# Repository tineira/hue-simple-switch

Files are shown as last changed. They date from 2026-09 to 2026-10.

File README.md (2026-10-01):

# hue-simple-switch

Wi‑Fi wall switch for the **Seeed XIAO ESP32-C6**. Calls the Hue Bridge's local Clip v2 API (HTTPS). Not Zigbee.

GPIO channels (closed = pin to GND, `INPUT_PULLUP`):

| id | GPIO | default kind | label |
| --- | --- | --- | --- |
| `boot` | 9 | `momentary` | BOOT |
| `d0` | 0 | `maintained` | D0 |
| `d1` | 1 | `maintained` | D1 |
| `d2` | 2 | `maintained` | D2 |
| `d3` | 21 | none | D3 |
| `d4` | 22 | none | D4 |
| `d5` | 23 | none | D5 |

D3–D5 (GPIO 21–23) are channels since 0.5.0, so one board takes up to six wall switches or buttons on D0–D5, plus BOOT. None of D3–D5 is a strapping pin, and this firmware has no I2C on D4/D5. D6–D10 stay unused (D6 is the chip's serial TX at boot).

Since 0.3.0 the console picks each channel's kind (`maintained` = toggle switch, `momentary` = push button) and sends it in the config's `channels[]`; a pin it does not list does nothing. BOOT is always a push button. The default kinds above apply only to the old config payload (no `channels[]`), from a console that predates channel types; there D3–D5 do nothing, so an unwired pin never acts.

Each channel has recipes per event, derived by the console:

- Toggle switch, flip set (the lever sets on or off; no `flip` in `channels[]`): `on` (lever closes), `off` (lever opens, after the ~400 ms double-click window), `double_click` (opens and closes inside the window; runs `on` when there is no `double_click` recipe).
- Toggle switch, flip toggle (`"flip": "toggle"`, since 0.8.0; each flip toggles, the console sends `toggle` for both `on` and `off`): each flip posts `on` (lever closes) or `off` (lever opens) at once when there is no `double_click` recipe. With one, a flip either way waits ~400 ms: a second flip inside it is `double_click`, otherwise the first flip runs. No `on` fallback. A toggle that turned the lights off restarts the scene list. Boot, a config change or a change of the flip setting never toggles.
- Push button: `short` on release, at once when the channel has no `double_click` recipe; with one, a second press inside ~400 ms is `double_click` and an expired window is `short`. `hold` fires once at ~800 ms while pressed, only when the channel has a `hold` recipe.
- BOOT without a `hold` recipe: a 3 s press re-pairs with the Bridge. With one, the button never re-pairs (USB install only).
- A scene list (`recall_scene` with `targets[]`) cycles from the last scene the channel set (kept in NVS), wraps, skips scenes that answer 404, and starts over at the first scene after an `off` on the channel (in flip toggle mode, after a toggle that turned the target off).

The GPIO runs NVS → Bridge; it doesn't wait for Vercel. Since 0.5.0 the config is stored as one NVS blob per channel, so saving the largest config (seven channels with scene lists) needs only one channel's worth of free space; the first boot after the update converts the older single blob.

Wiring for up to six wall switches or buttons on D0–D5: [`docs/wiring-switches.svg`](docs/wiring-switches.svg). Wire only the inputs you use. The step-by-step build guide (what to buy, wiring one input at a time, what never to connect, and when you need the resistors) is at [hue.tineira.com/how-to](https://hue.tineira.com/how-to?product=simple#wire).

To power the switch from the mains inside a wall box, behind the existing switch, there is a carrier board (KiCad, Gerbers for JLCPCB, BOM) and a printable enclosure in [`hardware/`](hardware/README.md). It keeps the same pins and firmware. It is an uncertified, experimental mains design: read its safety notes and have an electrician install it.

> [!WARNING]
> **Safety.** Mains voltage can kill. The designs in this repository are uncertified and some are unproven, and the maintainer is not an electrical engineer. Rules and wire colors differ by country. Read the [Safety notice](https://hue.tineira.com/safety) before you build anything, and never connect any pin of a USB-powered build to anything that is or was on mains. Everything here is provided as is, without warranty, as the licenses say.

**BOOT** (GPIO9) and **RST** (CHIP_PU) are **buttons**, not LEDs. The board has two lights:

The orange LED's alphabet is **implemented** in firmware 0.2.7: `docs/specs/finished/led-status.md`.

| Light | Where | Driven by |
| --- | --- | --- |
| Orange (user, GPIO15 `LED_BUILTIN`) | Right side, next to RST | This firmware |
| Red (charging) | Next to the USB-C | The charger hardware; the sketch doesn't touch it |

### Orange LED (firmware)

One pattern at a time, top to bottom. When the step changes, the burst starts from zero. `LOW` on GPIO15 turns the orange on (active low).

| What you see | Meaning |
| --- | --- |
| Solid on | System error: the console task wasn't created, or the console answered 401. The 401 stays solid until a response with a code other than 401, or a new `HUESET token`. Wins even without Wi‑Fi. |
| Continuous blink ~2 Hz (250 ms on / 250 ms off) | No Wi‑Fi STA, or Improv scan. Even with a saved SSID. |
| 2 flashes and a pause | Wi‑Fi ok, no console (URL or token empty, or a `your-…` placeholder). |
| 3 flashes and a pause | Wi‑Fi and console, Hue not paired, or pairing in progress / timed out. Holding BOOT 3 s (re-pair) uses this pattern. |
| 4 flashes and a pause | Wi‑Fi, console and Hue, no recipes. |
| One short flash every ~3 s | Armed: one or more recipes. |

Burst (#2–#4): 100 ms on, 200 ms between flashes, 1400 ms pause. The armed flash lasts 80 ms and repeats every 3 s.

### Red LED (charging, not the sketch)

| What you see | Meaning |
| --- | --- |
| On for ~30 s when USB is plugged in without a battery | USB present; then it turns off. |
| Blinking | LiPo battery connected and charging over USB. |
| Off with USB and battery | Charge complete (or no charge cycle). |

Contract: `hue-switch-console/docs/definitions.md` and `docs/device-api.md`.

## Setup

1. Flash and provision from Chrome on [hue.tineira.com](https://hue.tineira.com) → Devices (USB). Improv saves the **2.4 GHz** network and `HUESET` stores the token (`hsw_…`) and url in NVS `console`. None of that is compiled in. For development, copy `config.example.h` to `config.h` (only `SERIAL_DEBUG`); `arduino-cli upload` doesn't erase NVS, so the network and token survive every flash.
2. The XIAO discovers the Bridge (mDNS `_hue._tcp`, NVS, `discovery.meethue.com`) and pairs the Hue key (three orange flashes → Bridge button). IP and key stay in NVS, not in `config.h`.
3. Register: `POST /api/device/register` with `product: "simple"`, MAC, `channels[]` and snapshot (lights/rooms/scenes). Poll: `GET /api/device/config?mac=&rev=&firmware=` at boot, then every `X-Poll-Sec` seconds from the console (clamped 30 s to 1 h; `204` = unchanged, keep NVS), once more right after a new `rev` is saved, and 1 h after a `401`. Without the header (older console): ~1 min without recipes, 1 h with some. With recipes, register (topology) at most hourly.
4. Arduino IDE 2.3.10: open `hue-simple-switch.ino`, board **XIAO_ESP32C6**.
5. Or arduino-cli: `arduino-cli compile --profile xiao-c6 .`

List lamps (diagnostics):

```
curl -k -H "hue-application-key: KEY" https://BRIDGE_IP/clip/v2/resource/light
```

`config.h` is not committed. Product onboarding = the USB installer on hue.tineira.com.

## Release

A push to `main` **is a release**. `.github/workflows/firmware.yml` builds the product image and uploads it to the console (hue.tineira.com) with this version's `CHANGELOG.md` entry as release notes. The console's USB installer then offers that build to every Simple plugged in over USB, and since 0.6.0 the owner can send it over Wi-Fi from the Switches page (below). The workflow also keeps the `usb-installer` GitHub Release as a download link. Pushes that change only docs or the board design (`*.md`, `docs/`, `hardware/`) do not run it, except `CHANGELOG.md`, which re-sends the notes. To skip any other push, put `[skip ci]` in its commit message.

- `FIRMWARE_VERSION` in `console.h` is the version the console shows. Bump it for any change a board should pick up, and add its entry to `CHANGELOG.md` in the same commit. A push without a bump re-sends the notes only (`409 version_exists` warning).
- `THIRD_PARTY.json` lists the open-source components linked into the image (the core, ESP-IDF, and every library pinned in `sketch.yaml`), with version, SPDX license and a link to the license at that version. CI sends it as the release `credits` for the console's Credits page, and fails if any `platform:` or `libraries:` entry in `sketch.yaml` is missing from it or has a different version (`scripts/check-credits.py`, run on every pull request too). Update it in the same commit as any core or library bump.
- Update over Wi-Fi (0.6.0+, console `docs/specs/ota.md`): when the owner presses Update, the next poll's `200` carries `ota` (version, path, sha256, size). After the poll's connection is closed, the console task downloads `firmware.bin` from the console URL in NVS, writes it to the inactive app slot while hashing it, checks length and sha256, and restarts into it. It waits for the next poll while an input is pressed or a Hue call is queued or running. The new image confirms itself after its first `200`/`204` poll; a restart before that makes the bootloader go back to the old one, which reports `ota_error=boot`. A failure is reported once as `ota_error` and retried at most hourly (a download cut off by a power cut or restart counts, reported as `size` at the next boot, since 0.6.1) (`size`/`sha` from a bad image: not until reboot). NVS is never erased. Boards before 0.6.0 need one USB update first.
- Image layout and offsets: [`docs/firmware-artifacts.md`](docs/firmware-artifacts.md).
- The pipeline needs the `FIRMWARE_UPLOAD_TOKEN` secret in this repo. Setup and troubleshooting: the console repo's `README.md`, "Firmware release pipeline".

### Build and upload from a fork

A fork builds the same image on every push to its `main`, and can upload it to your own console instead of hue.tineira.com (self-hosting: the console repo's `docs/self-hosting.md`).

- **Build only (default).** With no `FIRMWARE_UPLOAD_TOKEN` secret, the workflow builds, skips the upload with a notice and stays green. The four installer parts are in the run's `usb-installer-simple` artifact and in the fork's `usb-installer` GitHub Release.
- **Upload to your console.** In the fork's **Settings → Secrets and variables → Actions**:
  1. Add the repository **variable** `CONSOLE_UPLOAD_URL` with your console's origin, for example `https://hue.example.com` (no path, no trailing slash). Without it, the upload goes to `https://hue.tineira.com`, which rejects a fork's token.
  2. Add the repository **secret** `FIRMWARE_UPLOAD_TOKEN` with the value of `FIRMWARE_UPLOAD_TOKEN` on your console.
  3. Push to `main` (or run the workflow by hand). The release waits in your console's `/admin` until you make it current; Setup then flashes it.
- Bump `FIRMWARE_VERSION` in `console.h` and add its `CHANGELOG.md` entry for each build you want boards to get, as above: your console keeps the first bins it received for a version.

## Contributing

See [`CONTRIBUTING.md`](CONTRIBUTING.md). Bugs and ideas go in GitHub issues.

## Sponsor

The console and the switch firmwares are free and stay that way. If they are useful
to you, you can [sponsor the project on GitHub](https://github.com/sponsors/tineira).
Sponsorship helps pay for development and does not unlock anything.

## License

Copyright (c) 2026 Tomas Neira and contributors. [MIT](LICENSE), except the
carrier board and enclosure designs in `hardware/`, which are
[CERN-OHL-P-2.0](hardware/LICENSE) (see [`hardware/README.md`](hardware/README.md)).

The image also links open-source components under their own licenses, listed in
[`THIRD_PARTY.json`](THIRD_PARTY.json). The Arduino-ESP32 core is LGPL-2.1-or-later:
because this firmware's source is public, you can rebuild it against a modified core.

The console this firmware talks to, [`hue-switch-console`](https://github.com/tineira/hue-switch-console),
is AGPL-3.0; it also holds the device contract (`docs/device-api.md`).

Not affiliated with or endorsed by Signify. Philips Hue is a trademark of Signify.

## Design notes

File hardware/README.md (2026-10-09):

# Mains carrier board and enclosure

A small board that puts the XIAO ESP32-C6 and its own power supply inside a wall
electrical box, powered from the mains, reading the existing wall switches or
buttons on D0 to D5. Firmware, pin map and console contract are unchanged: this
is the same `hue-simple-switch`, with a different way to power and wire it.

> [!WARNING]
> **Mains voltage can kill.** This is an uncertified design, produced with AI
> assistance and checked only by the design-rule tools listed below. It has not
> been tested by a lab and carries no approval mark (CE, UL, SEC or other).
> Have a qualified electrician install it. Switch the circuit off at the
> breaker before opening the box, and check it is dead with a tester.
> Build and install it at your own risk.
>
> - **Status: experimental.** The first boards came back from JLCPCB in
>   October 2026. One passed the checks in [TESTING.md](TESTING.md) and runs
>   on mains with the XIAO, showing in the console. None has been installed
>   in a wall yet. Expect mistakes.
> - The maintainer is not an electrical engineer. This is a hobby design.
> - Rules and wire colors differ by country and with the age of the wiring.
>   Identify every conductor by testing it, never by its color. In some
>   countries only a licensed electrician may change fixed wiring.
> - An uncertified device in your home's wiring may affect your home insurance.
>
> Read the full [Safety notice](https://hue.tineira.com/safety) before you order
> anything.

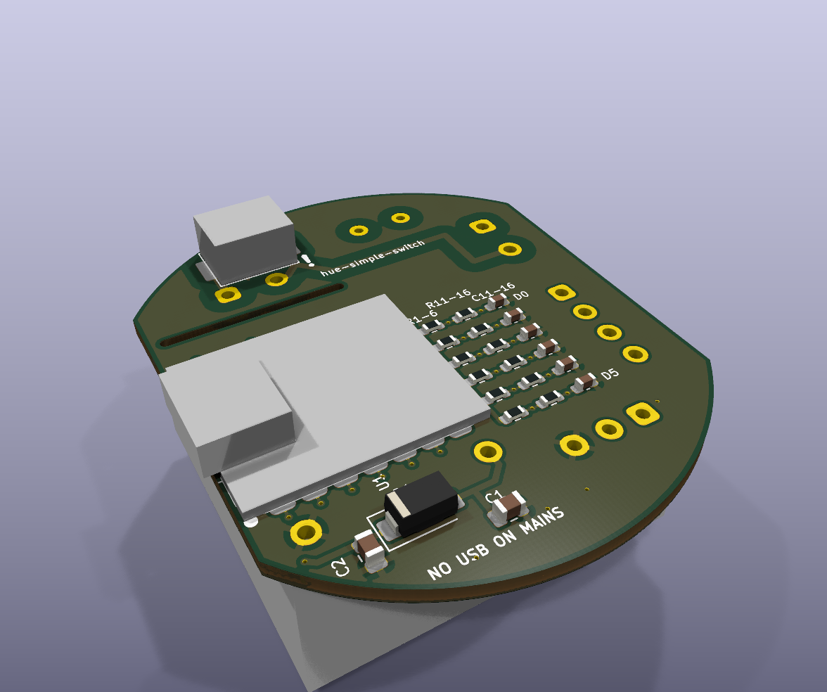
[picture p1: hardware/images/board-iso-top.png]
Top (XIAO side)

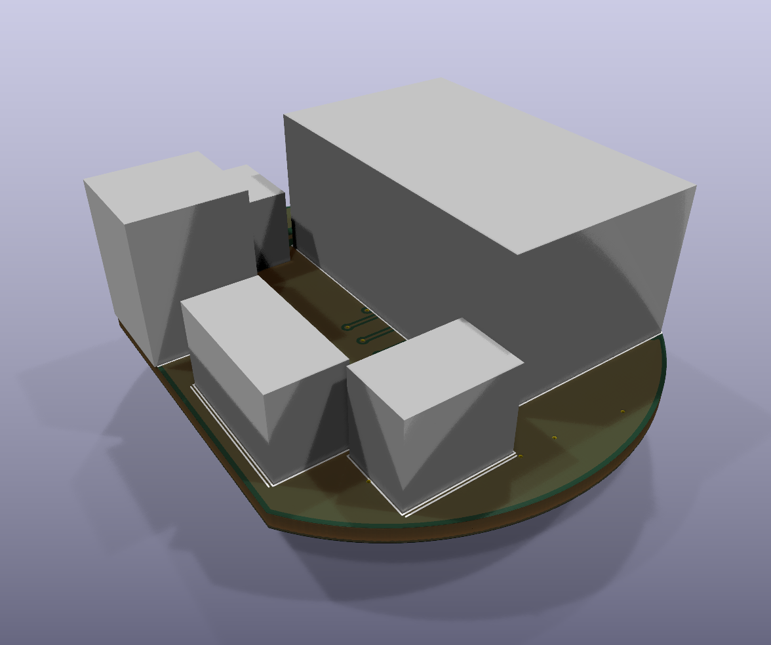
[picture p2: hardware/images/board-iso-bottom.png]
Bottom (power side)


The XIAO has no 3D model in these renders. It sits flat on the top side, USB-C
at the left edge.

## What is on the board

| Part | What it does |
| --- | --- |
| J1, 2-way 5.08 mm screw terminal | Mains in: L and N (up to 2.5 mm²) |
| F1, T500 mA TR5 fuse | Protects the wiring if the module or varistor fails |
| RV1, TDK SIOV CU3225 275 VAC SMD varistor (8.0 × 6.3 × 4.5 mm) | Clamps mains surges at the module input, after the fuse |
| PS1, Hi-Link HLK-PM01 | Certified, sealed, isolated 100-240 V AC to 5 V DC module (3 kV AC isolation) |
| D1, SS34 Schottky diode | Feeds the XIAO's 5V pin; stops a USB cable from powering the module backwards |
| U1, XIAO ESP32-C6 | Soldered flat by its edge pads |
| J2 + J3, 3.5 mm screw terminals | Wall switch inputs **D0 D1 D2 D3** and **D4 D5 GND**. Low voltage (3.3 V) only |
| R1-R6, R11-R16, C11-C16 | Each input: 10 kΩ pull-up at the pin, 1 kΩ in series, 10 nF at the terminal |

The pin map is the firmware's (see the repo [README](../README.md) and
[`docs/wiring-switches.svg`](../docs/wiring-switches.svg)): D0 to D5 are GPIO 0, 1,
2, 21, 22 and 23. A closed switch pulls its pin to GND. BOOT (hold 3 s to re-pair
with the Hue Bridge) and RESET are the XIAO's own buttons, reachable through the
window in the lid.

Isolation: everything connected to L or N is kept at least **6 mm** (clearance
and creepage, checked by DRC) from everything else. A routed slot under the
power module separates its AC pins from the XIAO. The only link between the two
sides is the HLK-PM01 itself.

The console's build guide has a short "can I use it?" check, a before-and-after wiring drawing and the installation order to show your electrician: [hue.tineira.com/how-to](https://hue.tineira.com/how-to?product=simple#in-wall).

Schematic: [`fab/hue-simple-switch-mains-schematic.pdf`](fab/hue-simple-switch-mains-schematic.pdf).

## Does it fit my box?

Enclosure outside: **46 × 56 mm, 26 mm tall** (a Ø56 mm disc with two sides cut
flat at 46 mm). It sits **behind the switch mechanism** in the same box, so the
box needs about 26 mm of free depth behind the mechanism.

| Box | Interior (typical) | Behind a mechanism |
| --- | --- | --- |
| EU round, Ø60 mm (DIN 49073) | Ø60 × 40 mm, or 60 to 65 mm deep | Deep box (≥ 60 mm) only. A standard 40 mm box is too shallow |
| US single gang | about 51 × 76 mm, 2.5 to 3.5 in deep | Yes, in most boxes |
| UK 86 × 86 (BS 4662) | 75 × 75 mm, 25, 35 or 47 mm deep | 47 mm box only |
| Chile, rectangular for Italian-style plates | about 50 × 95 mm, 40 to 50 mm deep | No room behind a mechanism, but it fits **beside** a 1-module mechanism, in the space of two blank modules (56 mm along the box) |

The Chilean dimensions come from retail listings, not a standard. Measure your
box: the width across the flats (46 mm) and the depth are what matter. In a
metal box, Wi-Fi range drops a lot; plastic boxes are better.

## Before you install: requirements

- **A neutral wire in the box.** The power module needs L and N. Many switch
  boxes (in Chile, and in older US and European homes) only have the switched
  live and the live feed, with no neutral. Without a neutral this board cannot
  be used. There is no safe no-neutral version for this design.
- **The Hue bulbs must be powered all the time.** The wall switch no longer
  switches the lamp; the lamp's live is joined straight through (as the
  existing Hue setup already requires).
- **The switch wires must be completely disconnected from the mains.** The
  wires that run from the box to each switch or button were mains wires. After
  the conversion they carry only 3.3 V from J2/J3. Every one of them must be
  disconnected from L, N and the lamp at both ends, and must go only to the
  switch and to J2/J3. If any of them still touches mains anywhere, the XIAO,
  and anyone touching its USB port, will be at mains voltage. An electrician
  must check this.

## Order assembled boards (JLCPCB)

JLCPCB assembles everything except the XIAO, on a panel of three boards.
All SMD parts are on the XIAO side (one-sided assembly); the power module, fuse
and terminals are through-hole on the other side.

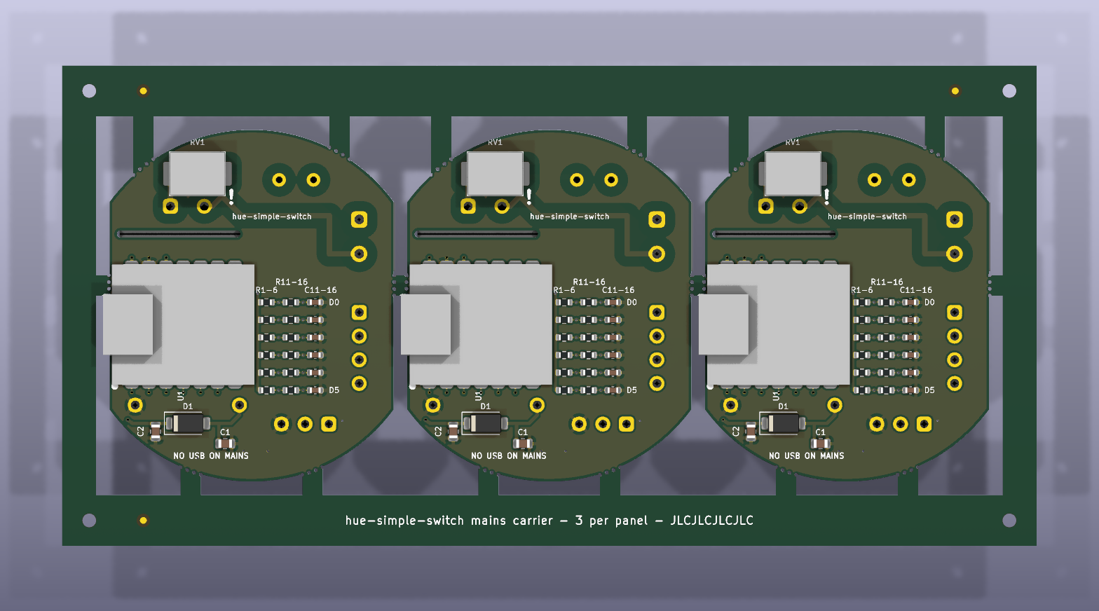
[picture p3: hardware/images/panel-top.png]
3-board panel


1. At jlcpcb.com, upload
   [`fab/jlcpcb/hue-simple-switch-mains-panel-gerbers.zip`](fab/jlcpcb/hue-simple-switch-mains-panel-gerbers.zip).
   The panel is 144 × 71 mm (three boards, a frame with fiducials and tooling
   holes; each board held on six tabs with mouse bites: two on each round end
   and one on each straight side, so the row stays stiff during assembly). Defaults: 2 layers, 1.6 mm FR-4,
   1 oz copper, HASL. Choose **Panel by customer** (the frame is already there,
   so no edge rails or panelizing by JLCPCB) and quantity **5** = 15 boards.
2. Turn on PCB Assembly, top side, and upload
   [`fab/jlcpcb/hue-simple-switch-mains-panel-bom.csv`](fab/jlcpcb/hue-simple-switch-mains-panel-bom.csv)
   and [`fab/jlcpcb/hue-simple-switch-mains-panel-cpl.csv`](fab/jlcpcb/hue-simple-switch-mains-panel-cpl.csv).
   Designators end in the board number (`R1_1`, `R1_2`, `R1_3`). The XIAO (U1)
   is not in them. Add through-hole assembly for PS1, F1 and J1-J3.
3. In the preview, check the parts listed under [Check in JLCPCB's
   preview](#check-in-jlcpcbs-preview). The CPL gives each part's centre (the
   middle of its pads), so parts should sit on their pads; rotate any that do not.
4. Small SMD parts need a few spares for machine loss (attrition). JLCPCB takes
   the basic resistors and capacitors from its stock; for the varistor (an
   extended part) have a couple more than 15 in your parts inventory.

To have JLCPCB assemble single boards instead of the panel, upload
[`fab/hue-simple-switch-mains-gerbers.zip`](fab/hue-simple-switch-mains-gerbers.zip),
[`fab/jlcpcb/hue-simple-switch-mains-single-bom.csv`](fab/jlcpcb/hue-simple-switch-mains-single-bom.csv)
(no XIAO) and [`fab/hue-simple-switch-mains-cpl.csv`](fab/hue-simple-switch-mains-cpl.csv).
The board is under JLCPCB's 70 × 70 mm minimum, so they add edge rails at extra cost.

For hand assembly, the single board is in
[`fab/hue-simple-switch-mains-gerbers.zip`](fab/hue-simple-switch-mains-gerbers.zip)
with [`fab/hue-simple-switch-mains-bom.csv`](fab/hue-simple-switch-mains-bom.csv)
and [`fab/hue-simple-switch-mains-cpl.csv`](fab/hue-simple-switch-mains-cpl.csv).

### Check in JLCPCB's preview

Parts with a polarity or a direction that matters:

| Part | What must be right |
| --- | --- |
| D1, SS34 diode (top) | Cathode band towards pad 1, the left pad (towards C2 and the board's left edge). Reversed, the XIAO gets no power |
| PS1, HLK-PM01 (bottom) | The two pins 5 mm apart (AC) at the mains end, next to the fuse and RV1; the two pins 15.4 mm apart (DC) at the other end. The pin pattern only fits one way, so if the preview shows pins off the holes, rotate it until all four land |
| J1, J2, J3, screw terminals (bottom) | The wire openings face the board edge: J1 and J2 towards the straight right edge, J3 towards the round end. Turned 180° they still fit the holes but face inwards, so check this one by eye (tilt the 3D view: the side you see from the middle of the board must be the back, not the metal clamps). JLCPCB's models for J2 and J3 are drawn the other way round from KiCad's, so the CPL already adds 180° to those two |
| U1, XIAO (you solder it) | Component side up, USB-C over the left board edge |

Not polarised: every resistor, the 10 nF and 22 µF ceramic capacitors, the
varistor RV1 and the fuse F1. They only need to sit on their pads.

When the panels arrive, snap the boards out at the mouse bites (bend each tab
towards the side without parts, or cut it with side cutters) and file the stubs
flush. Keep them clear of the mains parts: the tabs are at least 1 mm from any
mains copper.

## Check the board

Before the XIAO goes on and before the board sees mains, check it with a
multimeter: continuity on the mains side, isolation between mains and the
low-voltage side, the input resistors, and a first power-up through a lamp in
series. The steps, the expected readings and the readings from the first board
are in [TESTING.md](TESTING.md).

## Solder the XIAO

1. **Flash and set up the XIAO over USB before you solder it** (next section).
   It is easier on its own, and afterwards the board should not be on USB at the
   same time as mains.
2. Solder it flat on the top side, USB-C over the left board edge. Solder all 14
   edge pads (only D0-D5, 5V, GND and 3V3 are used; the others hold it in
   place). Do not let solder bridge to the bare pads under the XIAO; the board
   has no copper under it.
3. Inspect the mains side with a magnifier: no solder balls, splashes or flux
   bridges between L, N and anything else. Trim the through-hole leads on the
   top side to 1.5 mm or less so they do not touch the lid.

## First setup (USB, never on mains)

Do this with the board **not connected to mains** (before soldering the XIAO,
or with J1 disconnected):

1. Flash and provision it over USB-C like any other hue-simple-switch: Chrome
   on [hue.tineira.com](https://hue.tineira.com) → Devices (see the main
   [README](../README.md)). Then pair the Hue Bridge.
2. Unplug USB.

After installation, updates come over Wi-Fi (firmware 0.6.0 and newer), so USB
is never needed in the wall.

> [!CAUTION]
> **Never connect a USB cable while the board is connected to mains.** The power
> module is isolated, but a fault, a wrongly wired switch line or a damaged
> module would put mains on the USB cable and on your computer.

## Wire it

```text
 mains L (permanent live) ── J1 L          Hue lamps: live joined straight through,
 mains N ─────────────────── J1 N          not through the switch any more

 switch 1 ── J2 D0     switch 4 ── J2 D3
 switch 2 ── J2 D1     switch 5 ── J3 D4
 switch 3 ── J2 D2     switch 6 ── J3 D5
 other terminal of every switch, joined ── J3 GND
```

- Use only the inputs you need, and set each one up in the console (toggle
  switch or push button).
- The common return of all switches goes to the single GND terminal: join them
  first with a lever connector (for example WAGO 221) and bring one wire to J3.
- The screw terminals take up to 2.5 mm² (J1) and about 1 mm² (J2/J3). For
  1.5 mm² solid building wire on J2/J3, join a short 0.5-0.75 mm² flexible
  pigtail with a lever connector.
- Keep the switch wires on the low-voltage side of the enclosure (wire holes on
  the long straight side next to D0-D3, and the curved end next to D4-GND). The
  L/N holes are the two larger ones at the other end of the straight side.
- Earth (PE): the module does not need it. Connect the box's earth wires to each
  other as before, not to this board.

## Print the enclosure

- [`enclosure/enclosure-base.stl`](enclosure/enclosure-base.stl) and
  [`enclosure/enclosure-lid.stl`](enclosure/enclosure-lid.stl), both already
  oriented flat side down. No supports.
- Plastic: **not PLA** (it softens and creeps in a warm wall box). Use PETG, ASA
  or PC; ideally a flame-retardant (UL 94 V-0) grade. 0.2 mm layers, 3 walls,
  100 % infill for the floor.
- The board rests on posts in the base (power module down); the lid clicks over
  it and its posts hold the board down. The terminal screws are reached through
  the slots in the base floor. Tighten the wires before closing the lid, and
  put a strip of Kapton or electrical tape over the floor slots before the
  module goes into the wall.
- Source: [`enclosure/enclosure.scad`](enclosure/enclosure.scad) (OpenSCAD,
  parametric: wall, clearances, heights, hole sizes). The board as a 3D model is
  in `enclosure/hue-simple-switch-mains-board.step` for checking the fit in a
  CAD tool.

Layout of the enclosure, seen from the lid (XIAO side):

```text
            ┌─── round end ───┐
           /  MAINS: F1, RV1   \
          │  (module AC pins)   │  J1: L, N  ◄── two Ø3.6 wire holes
  USB-C ◄─┤  XIAO     ··········├─ J2: D0-D3 ◄── four Ø3.0 wire holes
 + window │  (over the module)  │
           \   J3: D4 D5 GND   /
            └──── ▼ three Ø3.0 wire holes
```

## Regenerate the files

Everything in `kicad/`, `fab/`, `images/` and the STLs is generated from
[`scripts/design.py`](scripts/design.py) (parts, nets),
[`scripts/layout.py`](scripts/layout.py) (placement, copper) and
[`scripts/footprints.py`](scripts/footprints.py) (footprints and height models
for the power module, varistor and terminal blocks, drawn from each
manufacturer's datasheet; the numbers are quoted in the file). Edit those, not
the KiCad files, then run with KiCad 10's own Python:

```bash
"$LOCALAPPDATA/Programs/KiCad/10.0/bin/python.exe" hardware/scripts/build_all.py
```

It writes the schematic and runs ERC, builds the PCB, refills the copper pours
and runs DRC with schematic parity (it stops on any error), then exports the
Gerber zip, BOM, CPL, PDFs, STEP, renders, builds the 3-board panel
([`scripts/build_panel.py`](scripts/build_panel.py)) and checks it with DRC
too, exports its JLCPCB files into `fab/jlcpcb/`, and, when OpenSCAD is
installed, the STLs. Reports: `fab/erc.rpt`, `fab/drc.rpt` (the remaining warnings are
silkscreen clipped at the board edge, which the fab trims anyway). The custom
6 mm rule is in `kicad/hue-simple-switch-mains.kicad_dru`.

You can also open `kicad/hue-simple-switch-mains.kicad_pro` in KiCad 10 to look
around; changes made there are lost at the next regeneration.

## Credits and licenses

- XIAO ESP32-C6 footprint: from Seeed Studio's
  [OPL_Kicad_Library](https://github.com/Seeed-Studio/OPL_Kicad_Library)
  (CC BY-SA 4.0), reduced to the 14 edge pads in `kicad/lib/XIAO.pretty`.
- Other symbols, footprints and 3D models: the KiCad libraries (CC BY-SA 4.0
  with the KiCad libraries exception).
- The board design and enclosure (`kicad/`, `fab/`, `enclosure/`, `images/`)
  are [CERN-OHL-P-2.0](LICENSE), a permissive open hardware license with a
  disclaimer written for physical hardware. The generator scripts in `scripts/`
  are software and stay MIT, like the rest of this repository.

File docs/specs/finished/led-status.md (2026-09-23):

# Simple switch — orange LED (status)

**Requirements** document. Covers only `hue-simple-switch` (XIAO ESP32-C6, GPIO15 `LED_BUILTIN`, orange). Round uses the disc, not this alphabet.

The red charging LED and the BOOT/RST buttons are not part of this spec.

**Status:** implemented (firmware 0.2.7). Spec archived. Not an implementation gap.

**Closed on 2026-09-21 (grilling):** tick during the POST, rejected key vs PUT, #6 only 401/task, burst restarts from zero. Do not reopen.

---

## 1. Who it's for

A **bench setup** checklist (the XIAO is visible). Inside the wall box the LED is hardly ever looked at; it's not everyday UI.

It doesn't teach *how* to configure. Only *which step you're on* or *there's a system fault*.

---

## 2. Steps (priority)

Evaluated **top to bottom**. The first that matches wins. One pattern at a time.

| # | Condition | Pattern |
| --- | --- | --- |
| 6 | **System** error (below) | Solid on |
| 1 | No Wi‑Fi STA (`WL_CONNECTED` false) | Continuous fast ~2 Hz |
| 2 | Wi‑Fi ok, no console URL or token in NVS `console` | **2** flashes, pause |
| 3 | Wi‑Fi + console, no paired Bridge (no usable Hue key in NVS, or pairing in progress / timed out) | **3** flashes, pause |
| 4 | Wi‑Fi + console + Hue, **zero** recipes in NVS | **4** flashes, pause |
| 5 | Armed: Wi‑Fi + console + Hue + ≥1 recipe | One short flash every ~3 s |

A 3 s BOOT hold (re-pair) shows **#3** while pairing lasts, not an extra pattern.

When the **step changes**, the pattern starts from zero (first flash, or the first half-cycle of #1/#5). The rest of a previous burst is not shown.

Improv scan or association (`WL_CONNECTED` false, even if NVS has an SSID) is **#1**. A token or URL that `consoleConfigured()` rejects (empty or malformed) is "no console" → **#2** if there is Wi‑Fi.

---

## 3. Timing (countable, not different frequencies)

Constants (ms), one table in code:

| Symbol | ms | Use |
| --- | --- | --- |
| `PULSE_ON` | 100 | Burst flash (#2–4) |
| `PULSE_GAP` | 200 | Off between flashes of the same burst |
| `BURST_PAUSE` | 1400 | Off after the last flash, before repeating |
| `FAST_ON` / `FAST_OFF` | 250 / 250 | #1 (~2 Hz). Not counted. |
| `HEART_ON` | 80 | #5 |
| `HEART_OFF` | 2920 | #5 → 3 s period |

Burst of *n* flashes: `n × PULSE_ON + (n − 1) × PULSE_GAP`, then `BURST_PAUSE`.

Example #3: on 100 — off 200 — on 100 — off 200 — on 100 — off 1400 — repeat. You count **three**.

#6: pin `LOW` (on), no blink tick.

Don't use 5 Hz vs 10 Hz vs 1 Hz. A human can't tell them apart on a 3 mm LED.

---

## 4. What a system error is (#6)

Closed list. Nothing else turns on the solid light:

- The console task was not created.
- The console answered **401** (token rejected). Recipes in NVS are kept.

The 401 **sticks** until a real console response with a code **> 0 and other than 401**, or until a new `HUESET token`. An attempt that doesn't arrive (timeout, `code == -1`, Wi‑Fi down) does **not** clear it. While it sticks, the solid light wins even without Wi‑Fi (#1 is not shown).

**Not** #6:

- Pairing timeout or Bridge not found → **#3**.
- Wi‑Fi down, no sticky 401 → **#1**.
- Failed Hue PUT on a GPIO touch (on/off/double/short), or unreachable Bridge → **the LED doesn't change**.
- Console poll, `rev`, snapshot, debounce, any `LOG`.

---

## 5. Hue "paired"

For #3 vs #4/#5: there is a key in NVS that `hueLooksLikeKey` accepts **and** a Bridge IP. Do **not** GET Clip on every LED tick.

It is lost, dropping to **#3**, only if a Hue HTTP call **that sent the key** says it's no good: **401 or 403**, and the body isn't "link button not pressed". A 401/403 from a request without the key (`/api/config`, discovery) doesn't count. A PUT that did carry the key and returns 401/403 does drop to #3. A timeout, a 5xx or the Bridge being off do **not** drop the step. Never #6.

For **20 s** after the pairing POST has just delivered the key, a 401 or 403 does **not** drop to #3. The key just came out of the Bridge. A later call, outside those 20 s, does.

---

## 6. Empty recipes

#4 = `gRecipeCount == 0` (no channel). One recipe on a single channel is already armed (#5). Don't distinguish "the other three are missing".

---

## 7. Boot

After `pinMode(LED_BUILTIN, OUTPUT)` the same classifier runs. The first few hundred ms may look like #1 (no STA yet). There is no separate `UI_BOOT` screen.

USB Improv / `HUESET` add no pattern: no STA → #1; STA without token/url (not yet in NVS) → #2.

---

## 8. Done in 0.2.7

- LED tick on a timer, **no `delay()`**, every **~50 ms**, also during the pairing POST. The GPIO doesn't wait for the LED (`channelsPoll` first).
- Pattern #3 is set by the classifier, not `hueBlink`.
- Polarity: `LOW` = on (GPIO15, active low). `HIGH` turns it off.
- The red charging LED is untouched.
- `FIRMWARE_VERSION` 0.2.7. The README table matches.

Outside this slice: Round (disc), Improv copy, console.

---

## 9. Bench test (acceptance)

With the XIAO in view, without opening Serial:

1. No SSID / Wi‑Fi down → continuous ~2 Hz.
2. Wi‑Fi, delete or empty URL/token → count **2**.
3. Wi‑Fi + console, BOOT hold 3 s or no key → count **3**; pressing the Bridge button moves to 4 or 5.
4. Paired, console without recipes → count **4**.
5. One recipe on any channel → one flash every ~3 s.
6. Invalid console token (401) → solid. Restore the token → back to 4 or 5.
7. During 4 or 5, a GPIO whose PUT fails → the pattern does **not** go solid.

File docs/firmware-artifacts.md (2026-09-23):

# Firmware artifacts (simple / ESP32-C6)

Product installer binary for hue.tineira.com. `SERIAL_DEBUG=0`. Wi-Fi, console URL and token are never compiled in: Wi-Fi is Arduino STA (Improv), token and URL go in NVS namespace `console` (`HUESET`). A dev `config.h` differs only in `SERIAL_DEBUG`.

## Compile

Sketch folder must be named `hue-simple-switch` (matches `hue-simple-switch.ino`). Profile: `sketch.yaml` `xiao-c6` (`esp32:esp32:XIAO_ESP32C6`, Arduino-ESP32 3.3.12). Partition table: sketch `partitions.csv` (min_spiffs: 1.9MB APP ×2, app at `0x10000`). USB CDC on boot is the board default.

```
copy config.product.h config.h
arduino-cli compile --profile xiao-c6 --export-binaries --build-property upload.maximum_size=1966080 .
```

`--export-binaries` writes under `build/esp32.esp32.XIAO_ESP32C6/`. `upload.maximum_size` matches the min_spiffs app slot (boards.txt still advertises the smaller default 4MB scheme).

Stage stable names in `dist/installer/` (gitignored; do not commit bins here):

| Export | Installer |
| --- | --- |
| `hue-simple-switch.ino.bootloader.bin` | `bootloader.bin` |
| `hue-simple-switch.ino.partitions.bin` | `partitions.bin` |
| `boot_app0.bin` | `boot_app0.bin` |
| `hue-simple-switch.ino.bin` | `firmware.bin` |

CI (`.github/workflows/firmware.yml`) copies `config.product.h` → `config.h`, compiles on push to `main` / `workflow_dispatch`, uploads those four files, and refreshes GitHub Release tag `usb-installer` (version `0.2.10`).

`FIRMWARE_VERSION` is `0.2.10` (see `console.h`).

## Manifest parts

`chipFamily`: `ESP32-C6`. Offsets from this compile’s `flash_args` (esptool write order). Do not erase flash (NVS survives).

| Part | File | Offset |
| --- | --- | --- |
| bootloader | `hue-simple-switch.ino.bootloader.bin` | `0x0` |
| partitions | `hue-simple-switch.ino.partitions.bin` | `0x8000` |
| boot_app0 | `boot_app0.bin` | `0xe000` |
| app | `hue-simple-switch.ino.bin` | `0x10000` |

Recorded from `arduino-cli compile --profile xiao-c6 --export-binaries` on 2026-09-20, core 3.3.12, `flash_args`:

```
--flash-mode dio --flash-freq 80m --flash-size 4MB
0x0 hue-simple-switch.ino.bootloader.bin
0x8000 hue-simple-switch.ino.partitions.bin
0xe000 boot_app0.bin
0x10000 hue-simple-switch.ino.bin
```

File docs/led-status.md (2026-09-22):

# Simple switch — LED naranja (status)

Documento de **requisitos**. **Implementado en firmware 0.2.7.** Cubre solo `hue-simple-switch` (XIAO ESP32-C6, GPIO15 `LED_BUILTIN`, naranja). Round usa el disco, no este alfabeto.

El LED rojo de carga y los botones BOOT/RST no forman parte de este spec.

**Estado (2026-09-21):** implementado en firmware 0.2.7.

**Cerrado el 2026-09-21 (grilling):** tick durante el POST, key rechazada vs PUT, #6 solo 401/task, ráfaga desde cero. No reabrir.

---

## 1. Para quién

Checklist de **alta en el banco** (se ve el XIAO). En la caja de la pared el LED casi no se mira; no es UI de uso diario.

No enseña *cómo* configurar. Solo *en qué peldaño estás* o *hay un fallo de sistema*.

---

## 2. Peldaños (prioridad)

Se evalúa **de arriba abajo**. El primero que cumpla gana. Un solo patrón a la vez.

| # | Condición | Patrón |
| --- | --- | --- |
| 6 | Error de **sistema** (abajo) | Encendido fijo |
| 1 | Sin Wi-Fi STA (`WL_CONNECTED` falso) | Rápido continuo ~2 Hz |
| 2 | Wi-Fi ok, sin `CONSOLE_URL` o sin `CONSOLE_TOKEN` (config.h ni NVS) | **2** destellos, pausa |
| 3 | Wi-Fi + consola, sin Bridge pareado (no hay key Hue usable en NVS, o pairing en curso / timeout) | **3** destellos, pausa |
| 4 | Wi-Fi + consola + Hue, **cero** recetas en NVS | **4** destellos, pausa |
| 5 | Armado: Wi-Fi + consola + Hue + ≥1 receta | Un destello corto cada ~3 s |

Hold 3 s en BOOT (re-pair) entra en **#3** mientras dura el pairing, no un patrón extra.

Al **cambiar de peldaño**, el patrón empieza de cero (primer destello, o el primer semiciclo de #1/#5). No se muestra el resto de una ráfaga anterior.

Scan Improv o asociación (`WL_CONNECTED` falso, aunque la NVS tenga SSID) es **#1**. Un token o URL que `consoleConfigured()` rechaza (vacío, o el placeholder `your-…` de `config.h`) es “sin consola” → **#2** si hay Wi-Fi.

---

## 3. Timing (contable, no Hertz distintos)

Constantes (ms), una sola tabla en código:

| Símbolo | ms | Uso |
| --- | --- | --- |
| `PULSE_ON` | 100 | Destello de ráfaga (#2–4) |
| `PULSE_GAP` | 200 | Apagado entre destellos de la misma ráfaga |
| `BURST_PAUSE` | 1400 | Apagado después del último destello, antes de repetir |
| `FAST_ON` / `FAST_OFF` | 250 / 250 | #1 (~2 Hz). No se cuenta. |
| `HEART_ON` | 80 | #5 |
| `HEART_OFF` | 2920 | #5 → periodo 3 s |

Ráfaga de *n* destellos: `n × PULSE_ON + (n − 1) × PULSE_GAP`, luego `BURST_PAUSE`.

Ejemplo #3: on 100 — off 200 — on 100 — off 200 — on 100 — off 1400 — repetir. Se cuentan **tres**.

#6: `digitalWrite` LOW, sin tick de parpadeo.

No usar 5 Hz vs 10 Hz vs 1 Hz. Un humano no los distingue en 3 mm.

---

## 4. Qué es error de sistema (#6)

Lista cerrada. Nada más enciende el fijo:

- La task de consola no se creó.
- La consola respondió **401** (token rechazado). Las recetas en NVS se conservan.

El 401 queda **pegado** hasta una respuesta real de la consola con código **> 0 y distinto de 401**, o hasta un `HUESET token` nuevo. Un intento que no llega (timeout, `code == -1`, Wi-Fi caído) **no** despega el fijo. Mientras siga pegado, el fijo gana aunque no haya Wi-Fi (no se ve #1).

**No** son #6:

- Timeout de pairing o Bridge no encontrado → **#3**.
- Wi-Fi caído, sin 401 pegado → **#1**.
- PUT Hue fallido en un toque GPIO (on/off/double/short), o Bridge inalcanzable → **el LED no cambia**.
- Poll de consola, `rev`, snapshot, debounce, un `LOG` cualquiera.

---

## 5. Hue “pareado”

Para #3 vs #4/#5: hay key en NVS que `hueLooksLikeKey` acepta **y** hay IP de Bridge. **No** hacer GET Clip en cada tick del LED.

Eso se pierde, y se pasa a **#3**, solo si un HTTP Hue dice que la key no sirve: **401 o 403**, y el cuerpo no es “link button not pressed”. Un PUT fallido, un timeout o el Bridge apagado **no** bajan el peldaño. No #6.

---

## 6. Recetas vacías

#4 = `gRecipeCount == 0` (ningún canal). Una receta en un solo canal ya es armado (#5). No distinguir “faltan los otros tres”.

---

## 7. Arranque

Tras `pinMode(LED_BUILTIN, OUTPUT)` corre el mismo clasificador. Los primeros cientos de ms pueden verse como #1 (aún no hay STA). No hay pantalla `UI_BOOT` aparte.

USB Improv / `HUESET` no añaden patrón: sin STA → #1; STA sin token/url (aún en NVS) → #2.

---

## 8. Implementación (cuando se haga)

- Un tick de LED en el `loop` (o timer), **sin `delay()`**, al menos cada **~50 ms**. El GPIO no espera al LED (`channelsPoll` primero).
- El pairing Hue **no congela** ese tick. Hoy `huePairAppKey` hace `delay(400)` y `hueBlink` en el mismo hilo; al implementar, el POST no puede dejar el naranja quieto a mitad de ráfaga. El blink de pairing es el patrón #3 del clasificador, no un loop propio. Llamar al tick mientras se espera el HTTP.
- Polaridad: `LOW` = encendido (GPIO15, activo en bajo). `HIGH` apaga.
- No tocar el LED rojo de carga.
- Subir `FIRMWARE_VERSION` parche.
- Actualizar la tabla del README (la de “qué ves”) para que coincida. Borrar la semántica vieja (on = Wi-Fi).

Fuera de este recorte: Round (disco), Improv copy, consola.

---

## 9. Prueba de banco (aceptación)

Con el XIAO a la vista, sin abrir Serial:

1. Sin SSID / Wi-Fi down → continuo ~2 Hz.
2. Wi-Fi, borrar o vaciar URL/token → se cuentan **2**.
3. Wi-Fi+consola, hold 3 s BOOT o sin key → se cuentan **3**; pulsar el Bridge pasa a 4 o 5.
4. Pareado, consola sin recetas → se cuentan **4**.
5. Una receta en cualquier canal → un destello cada ~3 s.
6. Token consola inválido (401) → fijo. Restaurar token → vuelve a 4 o 5.
7. Durante 4 o 5, un GPIO cuyo PUT falle → el patrón **no** pasa a fijo.

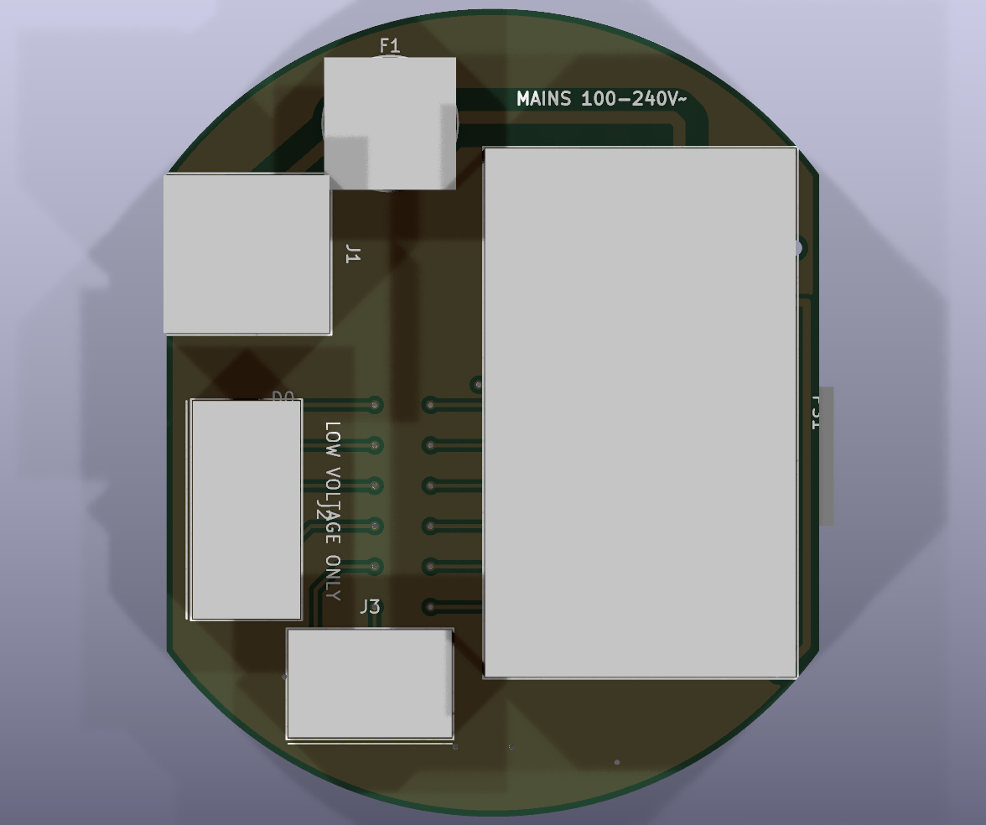
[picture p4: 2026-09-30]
hardware/images/board-bottom.png

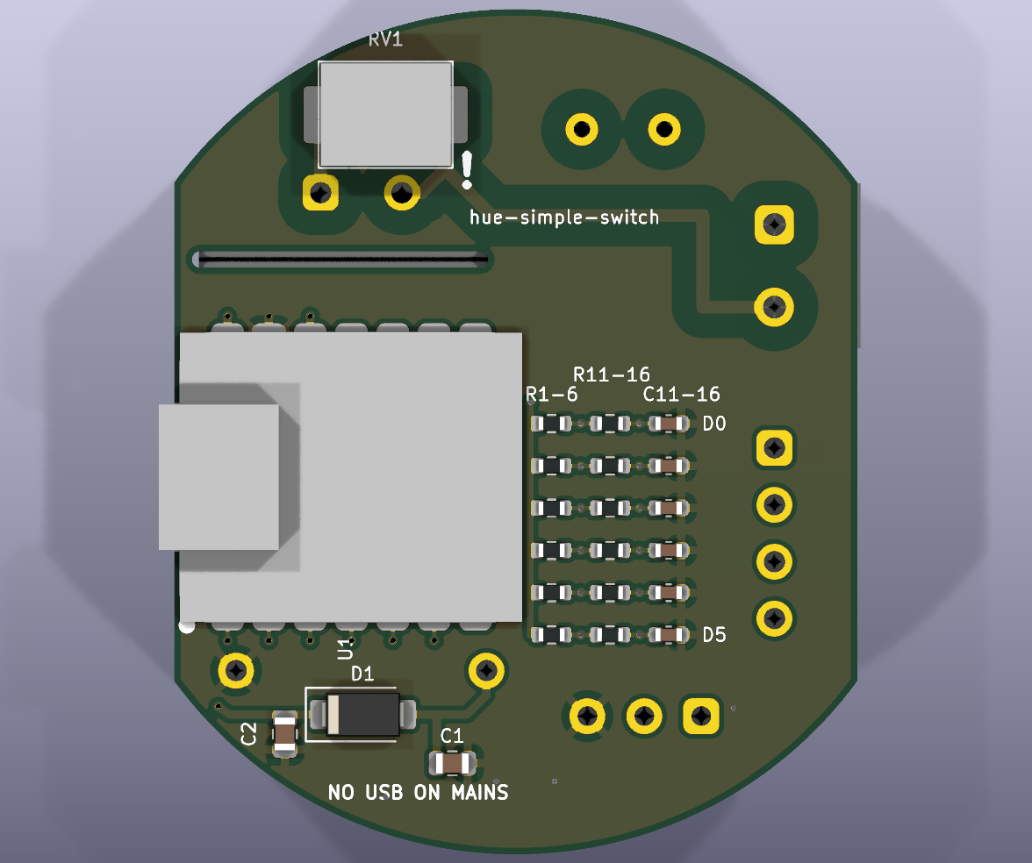
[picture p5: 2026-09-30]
hardware/images/board-top.png

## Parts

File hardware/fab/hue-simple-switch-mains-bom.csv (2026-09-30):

Comment | Designator | Footprint | LCSC Part # | Qty | Manufacturer part | Side | Notes
22uF 25V | C1,C2 | C_0805_2012Metric | C45783 | 2 | CL21A226MAQNNNE | top
10nF | C11,C12,C13,C14,C15,C16 | C_0603_1608Metric | C57112 | 6 | 0603B103K500NT | top | at the terminal side of the 1k: shunts noise picked up by the wall wiring
SS34 | D1 | D_SMA | C8678 | 1 | SS34 | top | blocks USB back-feed into the power module
T500mA 250V | F1 | Fuse_Littelfuse_372_D8.50mm | C142835 | 1 | Littelfuse 37205000001 (TR5 372, time-lag) | bottom
MAINS L/N | J1 | TerminalBlock_Kefa_KF128-5.08_1x02 | C474952 | 1 | KF128-5.08-2P (Cixi Kefa) | bottom | 300 V, 5.08 mm pitch, up to 2.5 mm2
D0 D1 D2 D3 | J2 | TerminalBlock_Xinlaiya_XY350V-3.5_1x04 | C557656 | 1 | XY350V-3.5-4P (Ningbo Xinlaiya) | bottom
D4 D5 GND | J3 | TerminalBlock_Kefa_KF350-3.5_1x03 | C474893 | 1 | KF350-3.5-3P (Cixi Kefa) | bottom
HLK-PM01 | PS1 | HiLink_HLK-PM01 | C209903 | 1 | Hi-Link HLK-PM01, 5 V 0.6 A, 3 kVAC isolation | bottom
10k | R1,R2,R3,R4,R5,R6 | R_0603_1608Metric | C25804 | 6 | 0603WAF1002T5E | top | pull-up, next to the pin
1k | R11,R12,R13,R14,R15,R16 | R_0603_1608Metric | C21190 | 6 | 0603WAF1001T5E | top | series, limits surge current into the pin
275VAC | RV1 | RV_TDK_SIOV_CU3225 | C211106 | 1 | TDK SIOV B72650M0271K072 (CU3225K275G2), 275 VAC, 8.0 x 6.3 x 4.5 mm | top | across the module input, after the fuse
XIAO ESP32-C6 | U1 | XIAO-ESP32-C6-SMD-EdgePads |  | 1 | Seeed Studio XIAO ESP32-C6 (113991254) | top | soldered flat by its castellated edge; not assembled by JLCPCB

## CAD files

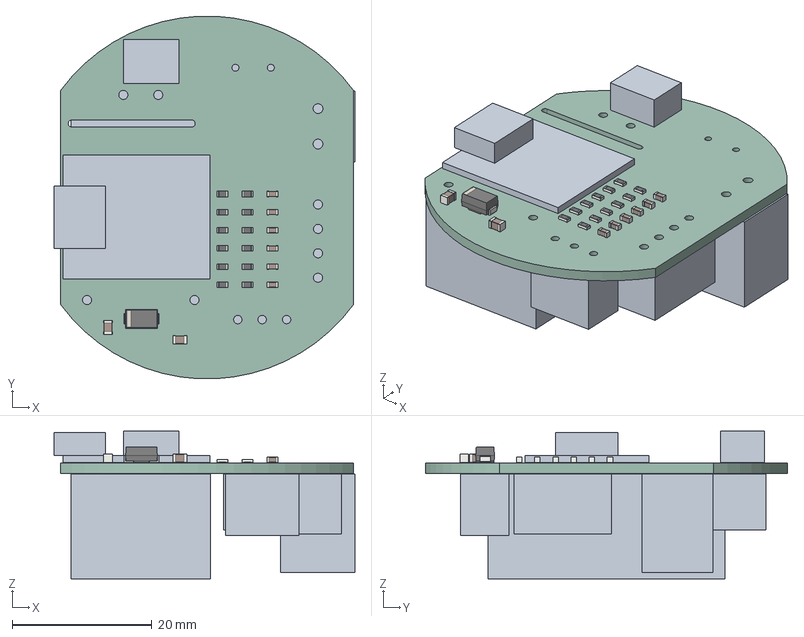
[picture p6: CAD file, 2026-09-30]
hardware/enclosure/hue-simple-switch-mains-board.step
43.1 x 51.9 x 21.2 mm
R_0603_1608Metric x 12
C_0603_1608Metric x 6
C_0805_2012Metric x 2
TDK_SIOV_CU3225_box
XIAO_ESP32C6_box
D_SMA
TerminalBlock_Kefa_KF128-5.08_1x02_box
HLK-PM01_box
Littelfuse_TR5_372_box
TerminalBlock_Xinlaiya_XY350V-3.5_1x04_box
TerminalBlock_Kefa_KF350-3.5_1x03_box
hue-simple-switch-mains_PCB

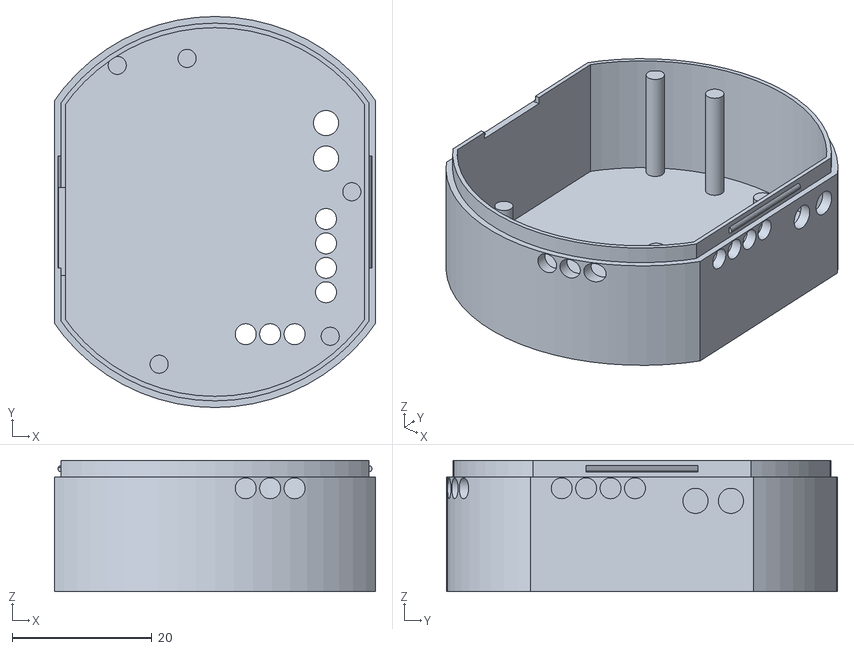
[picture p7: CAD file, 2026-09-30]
hardware/enclosure/enclosure-base.stl
46.0 x 56.0 x 18.8

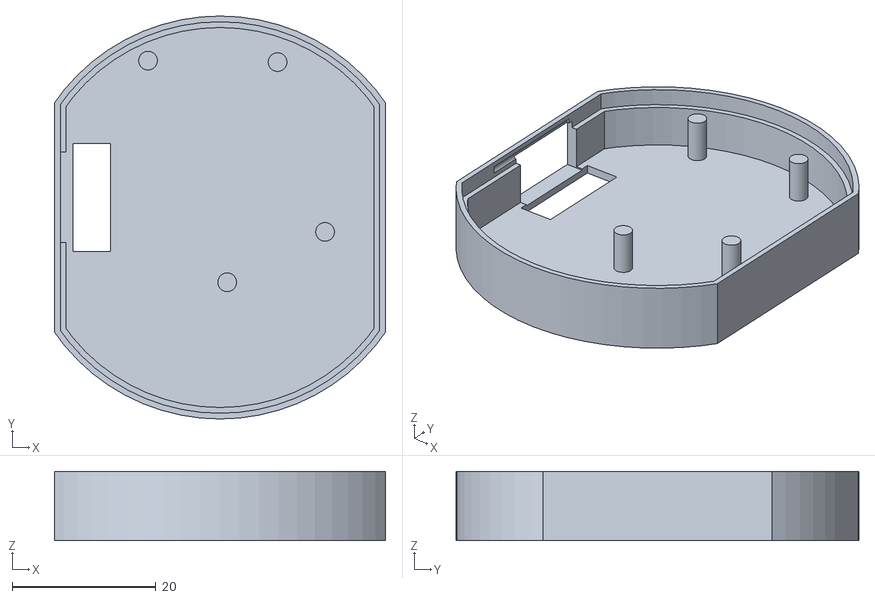
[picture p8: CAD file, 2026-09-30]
hardware/enclosure/enclosure-lid.stl
46.0 x 56.0 x 9.60

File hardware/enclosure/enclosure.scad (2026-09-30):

// hue-simple-switch mains carrier: printable enclosure (OpenSCAD 2021+).
//
// Two parts, printed flat side down, no supports:
//   base - the deep part under the board: power module, terminals, fuse.
//          Holds the board on posts. Wire holes in the side wall, screw
//          access holes in the floor.
//   lid  - the shallow cap over the XIAO. USB-C cut-out, window over the
//          BOOT/RESET buttons and the LED.
// The lid's skirt slides over a step at the top of the base wall and clicks
// onto two ridges on the straight sides.
//
// Render one part:  openscad -o base.stl -D 'part="base"' enclosure.scad
// Coordinates are the PCB's (mm from the board centre, x right, y DOWN as in
// KiCad); the model is mirrored at the end so it matches the real board seen
// from the XIAO side. z = 0 is the outside of the base floor.
//
// Print in a flame-retardant or at least heat-resistant plastic (PC, ASA,
// PETG; ideally a V-0 rated grade). Not PLA: it creeps when warm.

part = "both";          // "base", "lid", "both" (assembled view), "print" (both, side by side)

/* [Board] */
board_r      = 26.0;    // round ends
board_half_w = 21.0;    // straight sides at x = +-21
board_t      = 1.6;

/* [Enclosure] */
gap        = 0.4;       // board edge to inner wall
wall       = 1.6;
floor_t    = 1.2;
roof_t     = 1.2;
below      = 16.0;      // floor to board underside (power module is 15 mm)
above      = 6.0;       // board top to roof inside (XIAO + USB-C is ~4.5 mm)
step_h     = 2.4;       // height of the lid/base overlap
fit        = 0.15;      // clearance of the sliding fit, per side
post_d     = 2.6;

$fn = 64;

// derived
in_r   = board_r + gap;
in_w   = board_half_w + gap;
out_r  = in_r + wall;
out_w  = in_w + wall;
z_bb   = floor_t + below;          // board bottom
z_bt   = z_bb + board_t;           // board top
z_top  = z_bt + above + roof_t;    // outside of the roof
z_join = z_bt;                     // where the lid meets the base

echo(str("Outside: ", 2 * out_w, " x ", 2 * out_r, " mm, height ", z_top, " mm"));

// ---------------------------------------------------------------- features
// Wire entries (x or y of the terminal pins, from the PCB), z below the board.
// Opening heights from the Kefa KF128-5.08 and KF350-3.5 drawings.
j1_pins = [-12.74, -7.66];            // L, N at the right wall
j2_pins = [1.0, 4.5, 8.0, 11.5];      // D0..D3 at the right wall
j3_pins = [11.4, 7.9, 4.4];           // D4, D5, GND at the bottom (y+) wall
j1_hole = 3.6;  j1_z = z_bb - 4.2;
jl_hole = 3.0;  jl_z = z_bb - 2.4;

// Screwdriver access in the floor, over each terminal screw (the screws sit
// above the pins on these blocks): [x, y, length, width, angle]
screws = concat(
    [for (y = j1_pins) [15.9, y, 3.6, 3.6, 0]],
    [for (y = j2_pins) [15.9, y, 3.0, 3.0, 0]],
    [for (x = j3_pins) [x, 17.5, 3.0, 3.0, 90]]);

// Board supports, bottom side (free spots on the PCB)
base_posts = [[-14.0, -21.0], [-4.0, -22.0], [-8.0, 21.8], [19.6, -2.9], [16.5, 17.8]];
// Hold-downs from the roof, top side
lid_posts  = [[14.6, -2.0], [1.0, -9.0], [-10.0, 21.8], [8.0, 21.6]];

// USB-C on the XIAO (left edge) and the button/LED window
usb_y = 2.8;  usb_w = 12.6;  usb_h = 7.2;  usb_zc = z_bt + 1.0 + 1.6;
win   = [[-20.4, 2.8 - 7.5], [-15.2, 2.8 + 7.5]];   // x0,y0 .. x1,y1

// ---------------------------------------------------------------- shapes
module outline2d(r, w) { intersection() { circle(r = r); square([2 * w, 2 * r + 2], center = true); } }

module shell(z0, z1, r_out, w_out, r_in, w_in) {
    difference() {
        translate([0, 0, z0]) linear_extrude(z1 - z0) outline2d(r_out, w_out);
        translate([0, 0, z0 - 1]) linear_extrude(z1 - z0 + 2) outline2d(r_in, w_in);
    }
}

module wire_holes() {
    for (y = j1_pins) translate([in_w - 1, y, j1_z]) rotate([0, 90, 0]) cylinder(d = j1_hole, h = wall + 3);
    for (y = j2_pins) translate([in_w - 1, y, jl_z]) rotate([0, 90, 0]) cylinder(d = jl_hole, h = wall + 3);
    for (x = j3_pins) translate([x, 0, jl_z]) rotate([-90, 0, 0]) cylinder(d = jl_hole, h = out_r + 2);
}

module usb_cut() {
    translate([-out_w - 1, usb_y - usb_w / 2, usb_zc - usb_h / 2])
        cube([wall + gap + 2, usb_w, usb_h]);
}

// ---------------------------------------------------------------- base
module base() {
    difference() {
        union() {
            // floor
            linear_extrude(floor_t) outline2d(out_r, out_w);
            // wall, with the outer step at the top for the lid skirt
            shell(0, z_join - step_h, out_r, out_w, in_r, in_w);
            shell(z_join - step_h, z_join, out_r - wall / 2 - fit, out_w - wall / 2 - fit, in_r, in_w);
            // click ridges on the straight sides
            for (s = [-1, 1]) translate([s * (out_w - wall / 2 - fit), 0, z_join - step_h / 2])
                rotate([90, 0, 0]) cylinder(d = 0.9, h = 16, center = true, $fn = 16);
            // board supports
            for (p = base_posts) translate([p[0], p[1], 0]) cylinder(d = post_d, h = z_bb);
        }
        wire_holes();
        usb_cut();
        for (s = screws) translate([s[0], s[1], -1]) rotate([0, 0, s[4]])
            hull() for (d = [-1, 1]) translate([d * (s[2] - s[3]) / 2, 0, 0]) cylinder(d = s[3], h = floor_t + 2);
        // "MAINS" mark on the floor (reads correctly from outside, below)
        translate([-6, -10, -0.01]) linear_extrude(0.4)
            text("MAINS 100-240V~", size = 2.6, halign = "center", valign = "center", font = "Liberation Sans:style=Bold");
    }
}

// ---------------------------------------------------------------- lid
module lid() {
    difference() {
        union() {
            // roof
            translate([0, 0, z_top - roof_t]) linear_extrude(roof_t) outline2d(out_r, out_w);
            // wall above the joint
            shell(z_join, z_top, out_r, out_w, in_r, in_w);
            // skirt over the base step
            shell(z_join - step_h, z_join, out_r, out_w, out_r - wall / 2, out_w - wall / 2);
            // hold-downs
            for (p = lid_posts) translate([p[0], p[1], z_bt]) cylinder(d = post_d, h = z_top - z_bt);
        }
        usb_cut();
        // grooves matching the base ridges
        for (s = [-1, 1]) translate([s * (out_w - wall / 2 - fit), 0, z_join - step_h / 2])
            rotate([90, 0, 0]) cylinder(d = 1.1, h = 17, center = true, $fn = 16);
        // button / LED window over the XIAO's USB end
        translate([win[0][0], win[0][1], z_top - roof_t - 1])
            cube([win[1][0] - win[0][0], win[1][1] - win[0][1], roof_t + 2]);
        translate([4, -16, z_top - 0.4]) mirror([0, 1, 0]) linear_extrude(1)
            text("NO USB ON MAINS", size = 2.6, halign = "center", valign = "center", font = "Liberation Sans:style=Bold");
    }
}

// ---------------------------------------------------------------- output
mirror([0, 1, 0]) {
    if (part == "base") base();
    else if (part == "lid") translate([0, 0, z_top]) rotate([180, 0, 0]) lid();   // roof down for printing
    else if (part == "print") {
        base();
        translate([2 * out_w + 6, 0, z_top]) rotate([180, 0, 0]) lid();
    } else {
        color("SteelBlue") base();
        color("LightGray", 0.6) lid();
        color("DarkGreen") translate([0, 0, z_bb]) linear_extrude(board_t) outline2d(board_r, board_half_w);
    }
}

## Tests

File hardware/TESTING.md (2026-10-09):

# Check a board before it goes on mains

Checks for an assembled carrier board, done with a multimeter, before it is
connected to mains. They find assembly faults (a short, a missing part, a
reversed diode) and confirm the mains side is isolated from the low-voltage
side. Do them on every board, not one per batch.

Sections 1 to 3 are done **without mains and without USB**. Section 4 is the
first time the board is on mains; do it only when 1 to 3 pass. Do sections 1 to
4 **before soldering the XIAO** (the readings are cleaner), then section 5
once the XIAO is soldered.

All the through-hole parts (J1, J2, J3, F1, PS1) are on the bottom, so their
solder joints are on the top (XIAO) side. Probe those joints, not the terminal
screws: a loose clamp can read open.

## Finding the test points

Seen from the top (XIAO side), USB-C at the left edge. The shaded area is the
mains side.

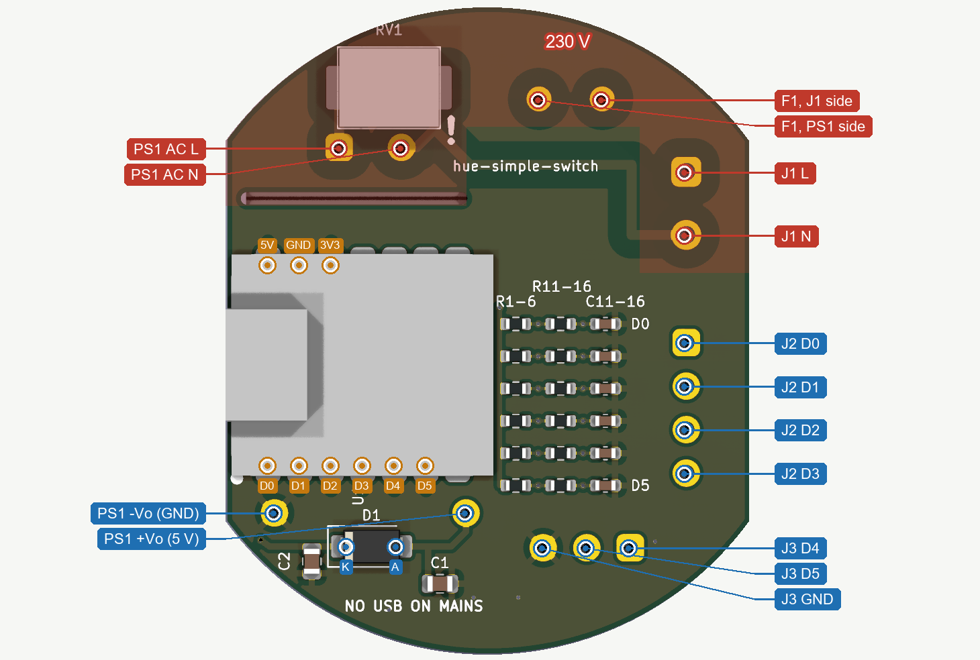
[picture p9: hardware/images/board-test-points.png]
Test points, top side


| Point | Where |
| --- | --- |
| J1 L, J1 N | The two large pads at the top right. L is the upper one (it goes to the fuse) |
| F1 | Two pads at the top, right of the varistor RV1 |
| PS1 AC L, AC N | The two pads 5 mm apart under RV1 (L on the left) |
| PS1 −Vo, +Vo | The two pads 15.4 mm apart along the bottom edge. −Vo (GND) is the one near the USB edge, +Vo (5 V) the one near C1 |
| D1 | Bottom left. Cathode (band) on the left pad, anode on the right pad |
| U1 D0 to D5 | The row of XIAO pads nearer D1. D0 is the one at the USB end, then D1, D2, ... D5 |
| U1 5V, GND, 3V3 | The other row of XIAO pads (towards the isolation slot), in that order from the USB end. The other four pads in that row are not connected |
| J2 D0 to D3 | Right edge, top to bottom |
| J3 D4, D5, GND | Bottom edge, right to left (GND is the leftmost) |
| R1–R6, R11–R16, C11–C16 | Three columns next to J2, one row per input, D0 at the top. Left column 10 kΩ (marked `01C`), middle 1 kΩ (`01B`), right 10 nF (tan, unmarked) |

The resistor markings are EIA-96 codes: `01C` = 100 × 100 = 10 kΩ, `01B` = 100 × 10 = 1 kΩ.

## 0. Look

With a magnifier:

- D1: cathode band on the left pad (towards C2 and the board edge). Reversed, the XIAO gets no power.
- Mains area (J1, F1, RV1, the AC pins of PS1, the slot): no solder balls, splashes or flux bridges.
- Through-hole joints of PS1, F1, J1, J2, J3: full fillets, no cold joints.
- J1, J2, J3: wire openings face the board edge.
- F1 is marked T500mA.

## 1. Mains side

| Check | Meter mode | Expected | Fault |
| --- | --- | --- | --- |
| J1 L to F1 (terminal side) | Continuity | Beeps, ≈ 0 Ω | Open |
| F1 across | Continuity | Beeps | Open: fuse |
| F1 (module side) to PS1 AC L | Continuity | Beeps | Open |
| J1 N to PS1 AC N | Continuity | Beeps | Open |
| J1 L to J1 N | Ω, 20 MΩ range | **Open**: no beep; OL, or rises to MΩ while the module's input capacitor charges | Beeps, or stays at a few Ω: short |

## 2. Isolation, mains to low voltage

The most important section. Ω, highest range. Hold the probes by the plastic
only and keep the board on a dry, insulating surface: fingers on both probes
read a few MΩ by themselves.

Every reading must **rise slowly and end at OL or tens of MΩ, the same on
every point**. The points on the low-voltage side are joined to each other
through kΩ resistors, so these are all one measurement: mains to the whole
low-voltage side, across the HLK-PM01. On the first boards, with a Fluke 83,
it rises for about a minute and ends near 24 MΩ, with or without the XIAO;
that is the module, not the board.

A reading that stops at a fixed value clearly lower than on other boards is a
leak. Clean the board with isopropyl alcohol (90 % or more), let it dry for an
hour, and measure again. A board with a leak does not go on mains.

- J1 L to J3 GND
- J1 N to J3 GND
- J1 L and J1 N to PS1 +Vo
- J1 L and J1 N to each input terminal, D0 to D5
- J1 L and J1 N to U1 5V
- With the XIAO soldered: J1 L and J1 N to the USB-C shell

A multimeter tests at a few volts and only finds hard shorts. An insulation
tester (500 V DC, L and N joined, against GND) is the real test; an
electrician may have one.

## 3. Low voltage

| Check | Meter mode | Expected | Fault |
| --- | --- | --- | --- |
| D1, red on the anode (right), black on the cathode (left) | Diode | 0.15 to 0.35 V; probes swapped: OL | OL both ways, or ≈ 0 |
| PS1 +Vo to −Vo | Ω, 2 MΩ range | Settles at kΩ or more, no beep | ≈ 0 Ω or beeps |
| U1 5V to U1 GND | Ω, 2 MΩ range | Settles at kΩ or more; less with the probes swapped | ≈ 0 Ω or beeps |
| J3 GND to PS1 −Vo, and to U1 GND | Continuity | Beeps | Open |
| Each input terminal to its own U1 pad (J2 D0 to U1 D0, ...) | Ω, 2 kΩ range | 1 kΩ (R11–R16) | Open or ≈ 0 |
| U1 3V3 to each U1 D0 to D5 pad | Ω, 20 kΩ range | 10 kΩ (R1–R6) | Open or ≈ 0 |
| Each input terminal to J3 GND | Ω, 2 MΩ range | No short; rises to OL (10 nF in between) | ≈ 0 Ω |
| J2 D0 to J2 D1 | Ω, **200 kΩ** range | ≈ 22 kΩ (1k + 10k + 10k + 1k through 3V3). Not a short | ≈ 0 Ω |
| U1 3V3 to U1 GND | Ω, 2 MΩ range | No short (OL without the XIAO) | ≈ 0 Ω |

The 5V and PS1 output readings move for a few seconds while C1 and C2 charge
from the meter, up or down. What matters is where they settle. The PS1 output
does not read open: the module's own regulation circuit is across it.

## 4. First time on mains (without the XIAO, without USB)

- Recommended: feed it through an incandescent lamp of 25 to 60 W in series
  (a "lamp limiter"), from a socket behind an RCD. If something is shorted, the lamp
  lights up fully and limits the current; on a good board it stays dark or
  barely glows.
- Clip the meter leads on before plugging in. Do not touch the board while it
  is plugged in.
- After unplugging, wait a minute before touching it: the module stays charged.

| Check | Meter mode | Expected | Fault |
| --- | --- | --- | --- |
| PS1 +Vo to −Vo | V DC, 20 V range | ≈ 5.0 V | 0 V, or above 5.5 V |
| D1 cathode to PS1 −Vo | V DC, 20 V range | 4.7 to 5.0 V. With no XIAO almost no current flows through D1, so it drops almost nothing; with the XIAO running it reads about 4.7 V | 0 V |

## 5. With the XIAO soldered

1. Clean the flux off the XIAO pads with isopropyl alcohol (90 % or more) and
   a toothbrush, without soaking the board. Let it dry for at least 30 minutes
   before any mains check.
2. Look again with a magnifier, above all between the U1 5V, GND and 3V3 pads,
   which sit next to each other.
3. Repeat section 2 completely, adding J1 L and J1 N to the USB-C shell. Same
   result as before.
4. The short checks below, without mains and without USB. The readings are
   lower than in section 3 now that the meter also sees the XIAO.
5. On mains, without USB: the XIAO starts, joins Wi-Fi and shows in the
   console's Devices list within seconds (if it was provisioned over USB
   first). The firmware does not use the XIAO's LEDs.

**Never connect USB while the board is on mains.**

| Check | Meter mode | Expected | Fault |
| --- | --- | --- | --- |
| U1 5V to U1 GND | Continuity, then Ω | No beep; settles at kΩ or more | Beeps |
| U1 3V3 to U1 GND | Continuity, then Ω | No beep; above about 100 Ω | Beeps |
| U1 5V to U1 3V3 | Continuity | No beep | Beeps: solder bridge |
| Each input terminal to its own U1 pad | Ω, 2 kΩ range | About 1 kΩ | Open |
| Each input terminal to J3 GND, and to its neighbour | Continuity | No beep | Beeps: solder bridge |
| On mains: D1 cathode to U1 GND | V DC, 20 V range | 4.6 to 4.9 V | 0 V |
| On mains: U1 3V3 to U1 GND | V DC, 20 V range | About 3.3 V | 0 V |

## Reference: first board

Board 1 of the first JLCPCB batch, 2026-10, measured with a Fluke 83.

| Check | Reading |
| --- | --- |
| J1 L to J1 N | Open, no beep |
| Isolation, every point in section 2 | Rises for about a minute, ends near 24 MΩ (same on a second board) |
| PS1 +Vo to −Vo | 1.6 kΩ |
| U1 5V to U1 GND, no XIAO | 2.5 MΩ (starts high, settles); probes swapped 38 kΩ |
| Input terminal to its own U1 pad | 1 kΩ |
| PS1 +Vo on mains, no XIAO | 5.0 V |
| D1 cathode on mains, no XIAO | 5.0 V |
| Section 5, XIAO soldered | Every check as expected; runs on mains and shows in the console |

If another board reads very differently from these, compare it with a third
one before deciding which is wrong.

## Mistakes that look like faults

- **≈ 21 kΩ from an input terminal to a U1 pad**: the probe is on another
  channel's pad (1 kΩ + 10 kΩ + 10 kΩ through 3V3). Move it to the pad of the
  same channel. The reading itself shows that both channels' resistors and the
  3V3 track are fine.
- **"1" at the left of the display**: on a manual-range meter this is over
  range, not open. 22 kΩ on the 20 kΩ range, or 1 kΩ on the 200 Ω range, both
  show it.
- **Open across a resistor**: a probe on the black body of an 0603 part does
  not touch metal. Press on the solder at each end. Then check the range.
- **A meter that reads open across a known 1 kΩ resistor is not usable for
  section 2.** It happened with the first board: one meter read every 1 kΩ
  input resistor as open, a second meter read them correctly.

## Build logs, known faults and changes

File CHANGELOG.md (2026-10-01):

# Changelog

User-facing release notes for the Simple switch (XIAO ESP32-C6 with wired buttons). One `### <version> — <YYYY-MM-DD>` heading per `FIRMWARE_VERSION`, newest first, written in the same commit that bumps `FIRMWARE_VERSION`, in the wording of the person using the switch. CI sends the entry for the current version to the console as the release notes.

Start a bullet with `Important: ` when the person must know or do something before or right after updating (a button to press, a setting to redo). The console shows those first, with an Important label, when Setup offers the update. Do not use it for new features.

### 0.8.0 — 2026-09-30

- A toggle switch can now toggle the lights on every flip, whichever way the lever moves, when you choose "Each flip toggles the lights" in the console. The lever can no longer disagree with the lights after they were changed from the Hue app or another switch, and two switches can share one light, as on a staircase.
- In that mode a quick flick and back recalls your scenes from either lever position. Without scenes, each flip toggles at once, with no wait.
- The switch never toggles the lights by itself when it starts, reconnects or gets new settings, so lights that came back on after a power cut stay on.

### 0.7.1 — 2026-09-29

- Hold to dim pauses for less time at full and at the lowest level before turning around.

### 0.7.0 — 2026-09-29

- Hold to dim now goes down and up in a loop until you let go, pausing briefly at full and at the lowest level, so you no longer let go and hold again to change direction.
- Hold to dim moves at the same speed from any level: a light near full gets there right away instead of creeping for several seconds.
- A hold brightens a light that is off or below about a third, and dims it otherwise, the same way every time.
- If the button stays held for more than 30 seconds, dimming stops by itself.

### 0.6.4 — 2026-09-29

- Scenes with many lights no longer go missing from the scene list in the console. Before, a scene that set a lot of lights at once was too large for the switch to read, and it was left out.

### 0.6.3 — 2026-09-29

- After a restart, the switch sends its lights, rooms and scenes to the console once instead of twice, so it asks less of the Hue Bridge and the console while starting up.

### 0.6.2 — 2026-09-28

- Nothing changes in how the switch works. This version is sent over Wi-Fi to check that an update cut off by a power cut is reported and then completes.

### 0.6.1 — 2026-09-28

- If the switch loses power or restarts in the middle of an update over Wi-Fi, the Switches page now shows that the update failed, and the switch tries again about an hour later. Before, it tried again right away without telling you.

### 0.6.0 — 2026-09-28

- After this update, the switch can get new versions over Wi-Fi: press Update next to it on the Switches page, and it updates itself at its next check-in, without leaving the wall. This update itself still goes over USB.
- The Switches page shows the version each switch is running, refreshed every time the switch checks in.
- If an update over Wi-Fi fails or the new version does not start properly, the switch keeps running the version it had, and the Switches page tells you the update failed.
- Your settings, Wi-Fi network and Hue pairing are kept through every update.

### 0.5.0 — 2026-09-28

- You can now wire up to six switches or buttons to one board, on pins D0 to D5.
- The new inputs D3, D4 and D5 do nothing until you set each one up in the console, as a toggle switch or a push button. Your settings for D0, D1 and D2 are kept.

### 0.4.4 — 2026-09-27

- The switch no longer risks restarting when you pair it with the Hue Bridge again, or clear its settings, while it is checking in with the console.

### 0.4.3 — 2026-09-27

- While one switch is waiting on a slow Hue Bridge, the other switches and buttons still respond right away.
- Quick flicks of a switch are no longer missed while the Bridge is busy with another one: the lights end up matching where you left each switch.
- A button press that could not reach the Bridge within about 10 seconds is dropped, instead of changing the lights long after you pressed it.

### 0.4.2 — 2026-09-27

- If the switch loses power or runs out of storage while saving new settings from the console, it now gets those settings again on its next check-in. Before, it could keep its old settings while the console showed it as up to date.

### 0.4.1 — 2026-09-26

- The console shows whether the switch has your latest settings.
- Changes you save in the console reach the switch in about 30 seconds while you are working on it, and in about 5 minutes otherwise, instead of up to an hour.

### 0.4.0 — 2026-09-25

- A push button can dim its lights while you hold it, if you choose Dim for its hold in the console. Let go to stop at the level you want.
- Each hold dims the other way from the last one. A light at full brightness always dims down, and one near its lowest always brightens.
- Holding to dim a light that is off turns it on at its lowest level and brightens it. Dimming down never turns a light off.

### 0.3.0 — 2026-09-25

- Each input can be a toggle switch or a push button, whichever you choose for it in the console.
- Important: An input you have not set up in the console does nothing. After updating, set up each wired input in Switches.
- A push button responds as soon as you let go, unless you gave it a double-click action.
- Double-clicking a toggle switch steps through your chosen scenes, one per double-click, and starts again from the first after you switch the lights off.
- Holding BOOT can run a Hue action instead of re-pairing with the Bridge, if you choose that in the console.

### 0.2.11 — 2026-09-24

- Important: After this update, installing new firmware from Setup no longer needs the BOOT button. Press RESET once when the write finishes.

### 0.2.10 — 2026-09-22

- Pairing with the Bridge no longer fails if the first check right after pairing does not go through.

### 0.2.9 — 2026-09-22

- The switch ignores a console token that is not a real API key.

### 0.2.8 — 2026-09-22

- Devices can read the switch's status, start pairing, and clear its saved settings over USB.

### 0.2.7 — 2026-09-22

- The orange LED shows the setup step as a count of blinks. See How-to.

### 0.2.6 — 2026-09-21

- The Wi-Fi network list during setup tries again if the first scan fails.

### 0.2.5 — 2026-09-21

- USB setup stays connected while you pick a Wi-Fi network.

### 0.2.4 — 2026-09-21

- USB setup still works right after the switch restarts.

### 0.2.3 — 2026-09-20

- The Wi-Fi network list during setup is more reliable while the switch is starting.

### 0.2.2 — 2026-09-20

- The switch answers a Wi-Fi scan request during setup straight away.

### 0.2.1 — 2026-09-20

- The Wi-Fi network list during setup is no longer empty when the scan is slow.

### 0.2.0 — 2026-09-20

- You can set up the switch from the console over USB: Wi-Fi and the console link are saved on the switch.

### 0.1.1 — 2026-09-20

- Buttons stay responsive while the switch checks in with the console. If a check-in fails, the switch keeps its last good settings.

### before 0.1.1 — 2026-09-19

- First Simple switch firmware. The BOOT button toggles a light, and the switch finds and pairs with the Hue Bridge.

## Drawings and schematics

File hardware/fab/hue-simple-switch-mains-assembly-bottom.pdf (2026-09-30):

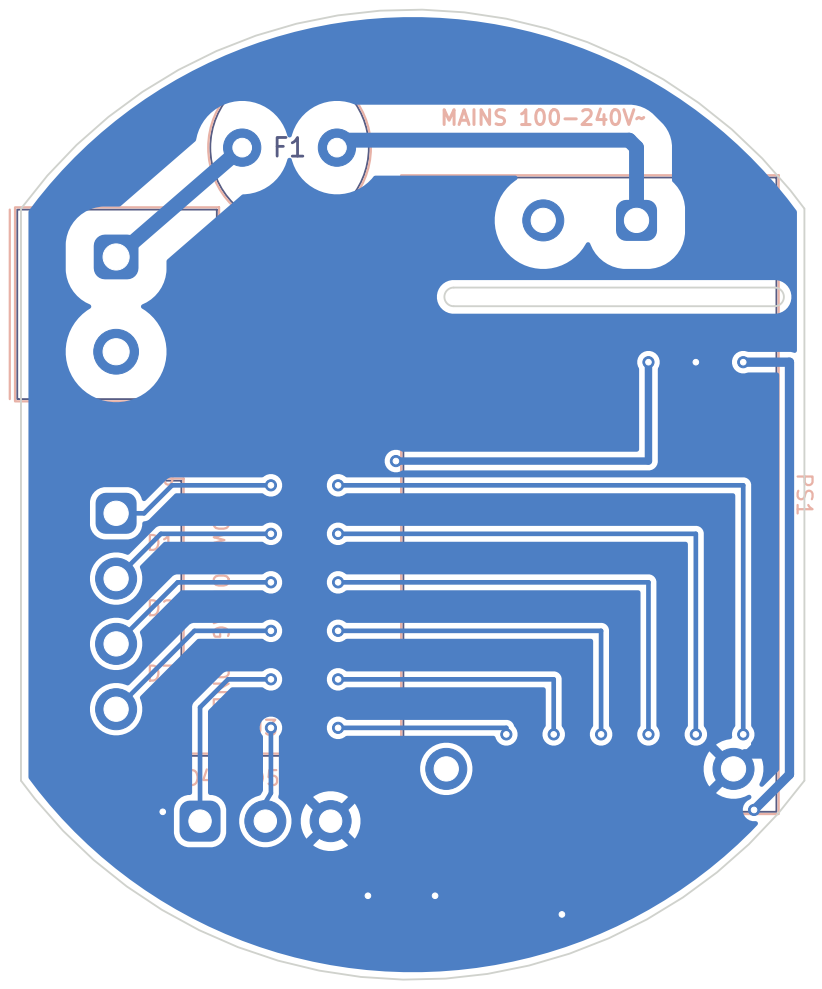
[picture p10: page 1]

Sheet:
File: hue-simple-switch-mains.kicad_pcb
Title:

Size: A4 | Rev:
KiCad E.D.A. 10.0.6 | Id: 1/1

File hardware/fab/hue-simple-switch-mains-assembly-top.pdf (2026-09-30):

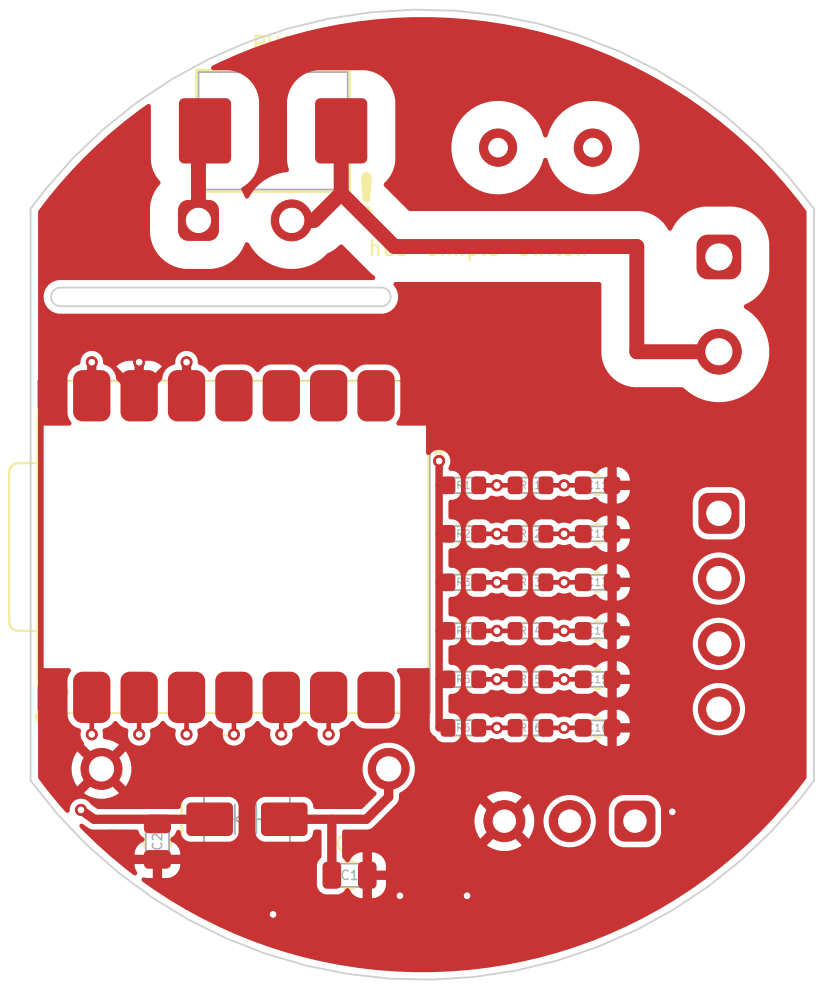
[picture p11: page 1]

hue-simple-switch R11-16C11-16D0D5 NO USB ON MAINS !

Sheet:
File: hue-simple-switch-mains.kicad_pcb
Title:

Size: A4 | Rev:
KiCad E.D.A. 10.0.6 | Id: 1/1

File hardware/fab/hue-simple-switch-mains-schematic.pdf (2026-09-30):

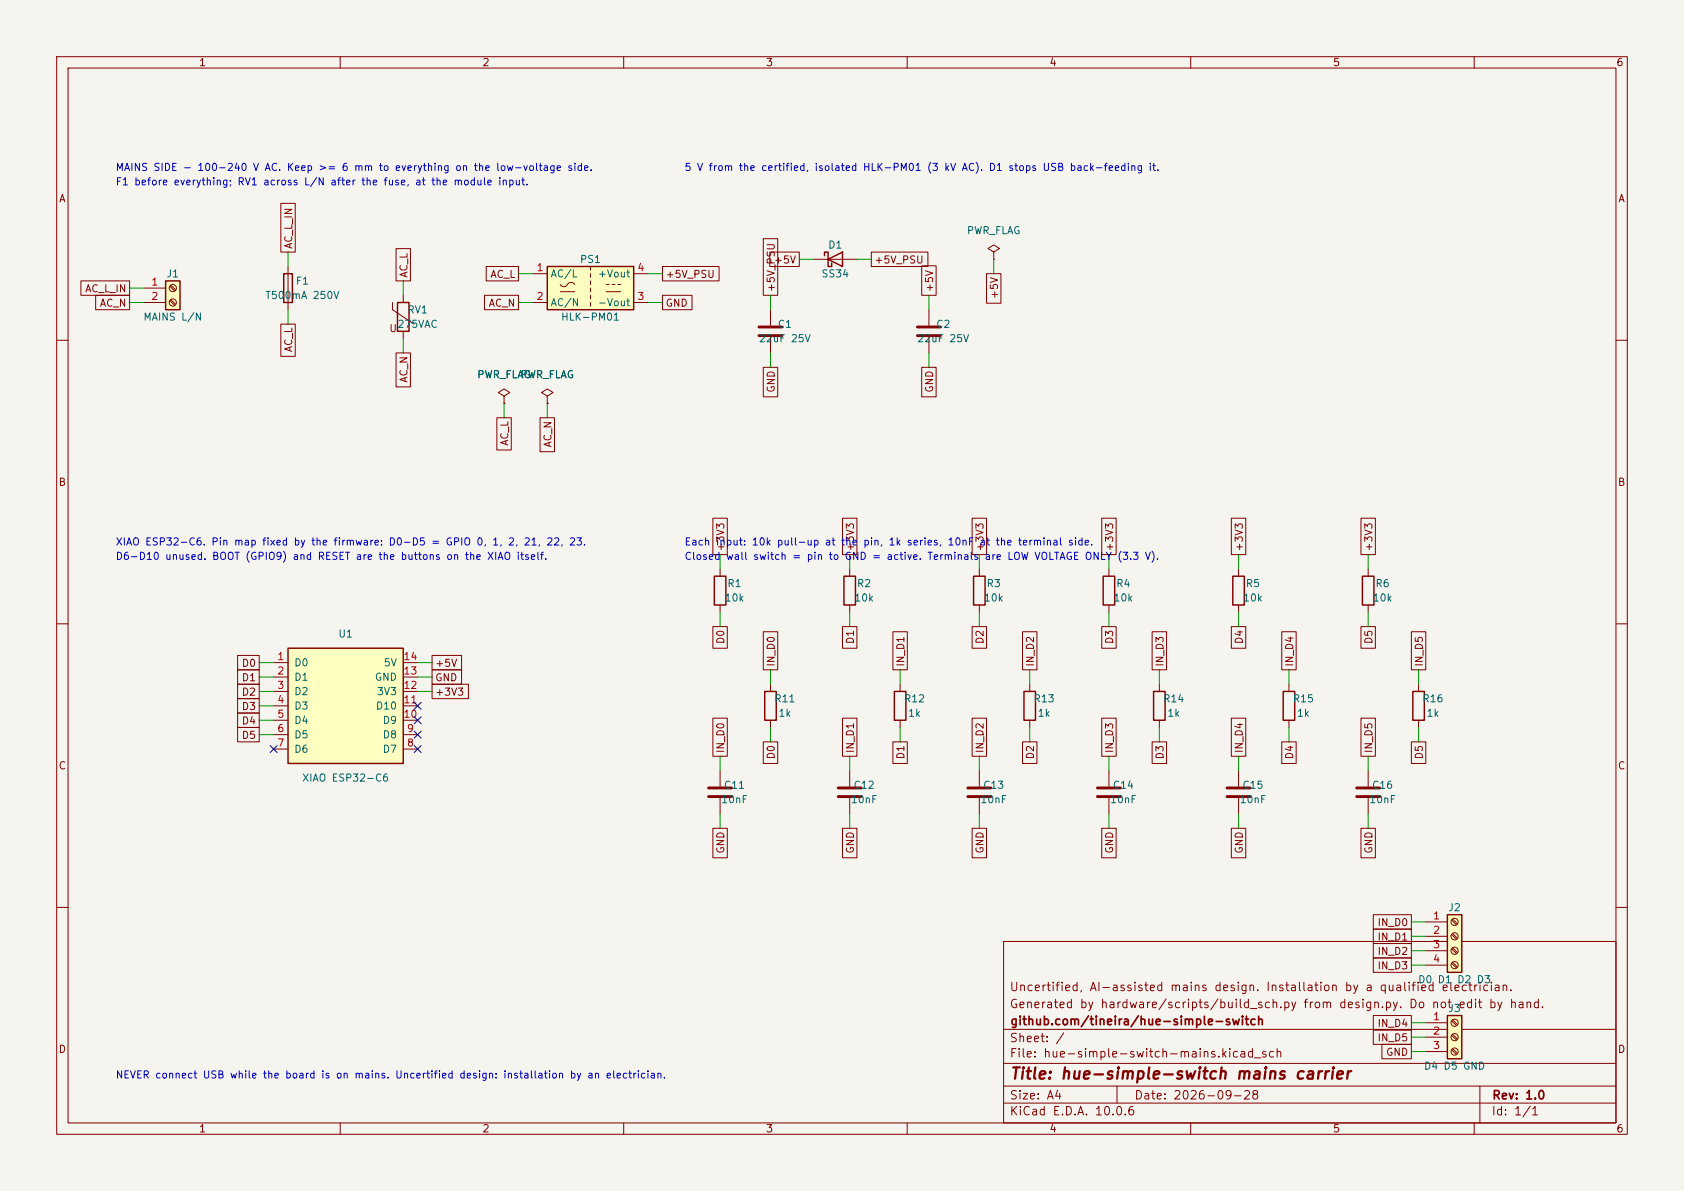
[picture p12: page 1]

3 IN_D2 Uncertified, AI-assisted mains design. Installation by a qualified electrician. Generated by hardware/scripts/build_sch.py from design.py. Do not edit by hand.

github.com/tineira/hue-simple-switch
Sheet: /
File: hue-simple-switch-mains.kicad_sch
Title: hue-simple-switch mains carrier

Size: A4 | Rev: 1.0
KiCad E.D.A. 10.0.6 | Id: 1/1

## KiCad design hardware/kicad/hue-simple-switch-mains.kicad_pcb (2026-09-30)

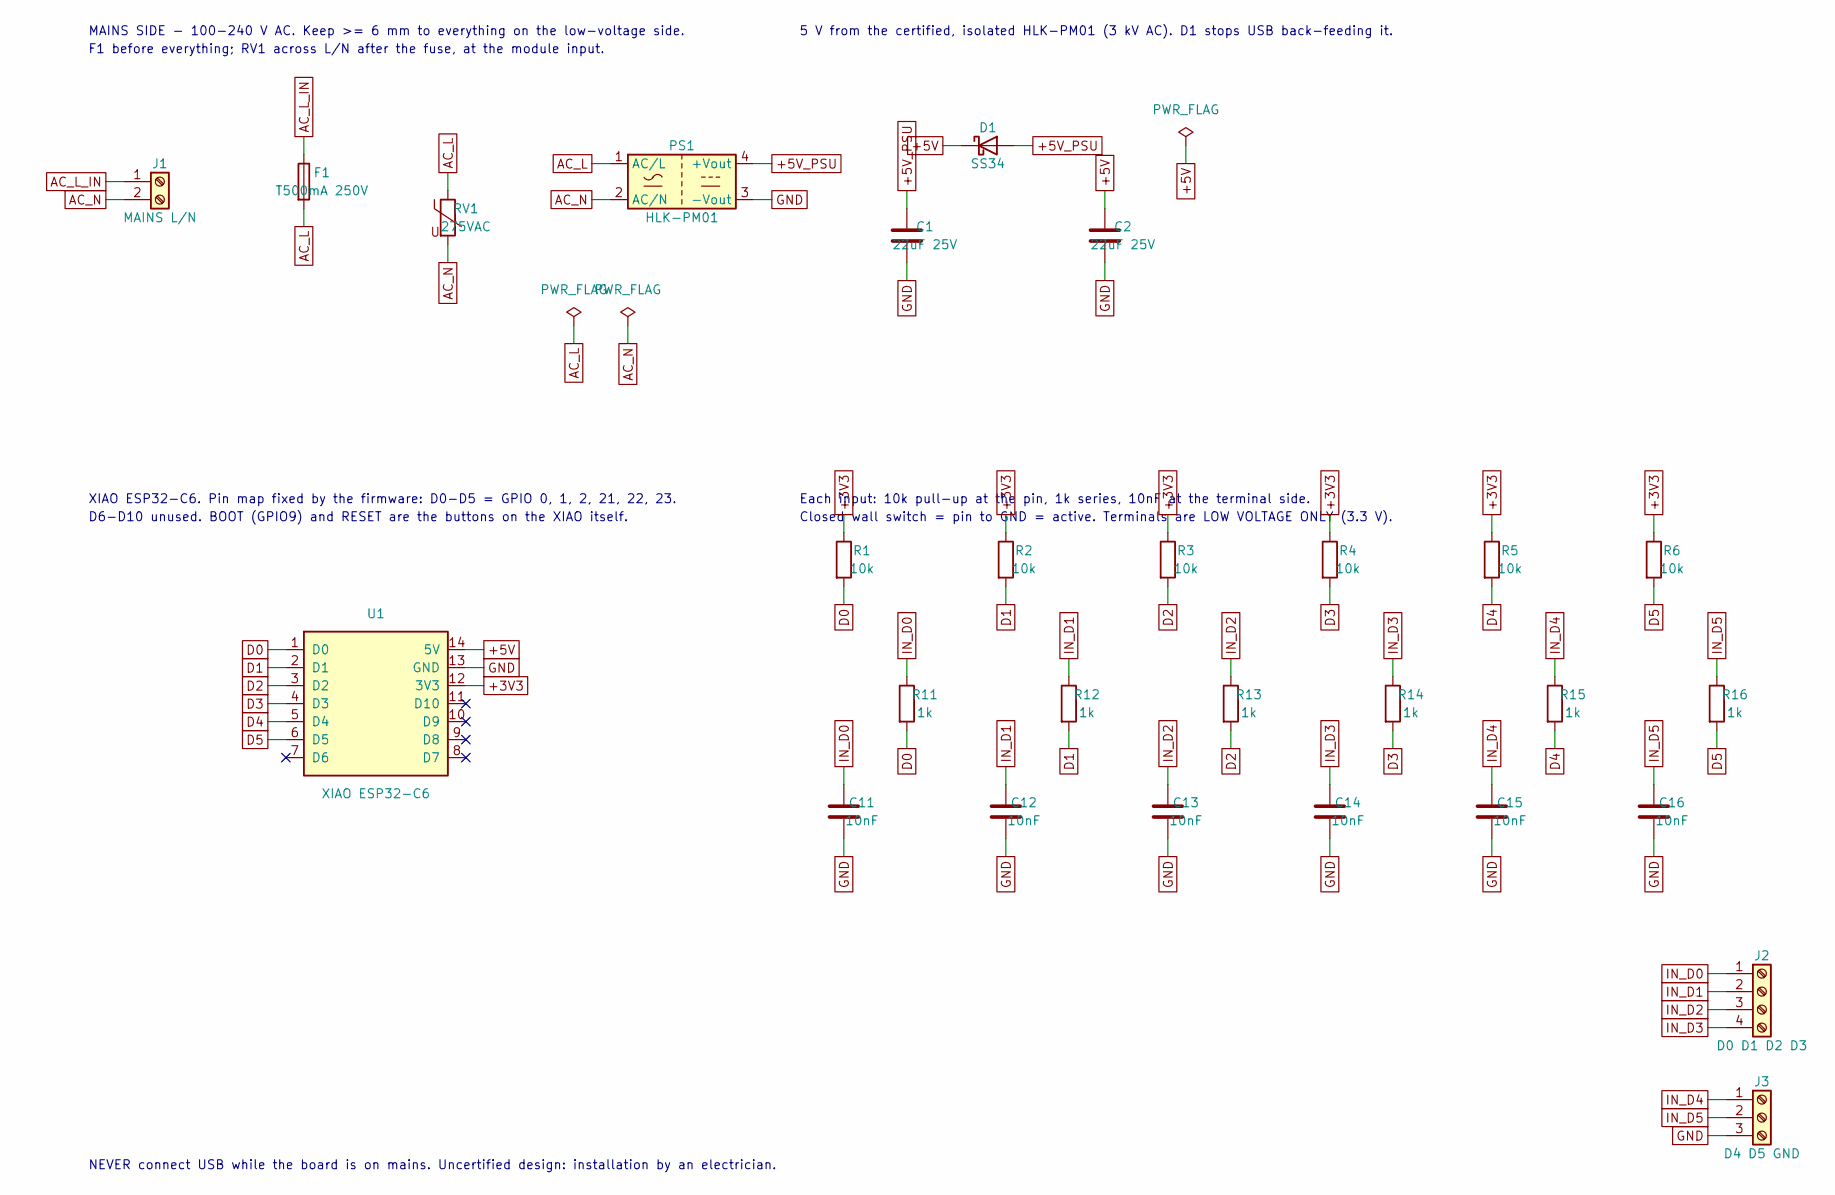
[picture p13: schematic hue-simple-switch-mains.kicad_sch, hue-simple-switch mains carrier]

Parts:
C1, C2: 22uF 25V; C_0805_2012Metric; MPN CL21A226MAQNNNE; LCSC C45783
C11, C12, C13, C14, C15, C16: 10nF; C_0603_1608Metric; MPN 0603B103K500NT; LCSC C57112
D1: SS34; D_SMA; MPN SS34; LCSC C8678
F1: T500mA 250V; Fuse_Littelfuse_372_D8.50mm; MPN Littelfuse 37205000001 (TR5 372, time-l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; LCSC C142835
J1: MAINS L/N; TerminalBlock_Kefa_KF128-5.08_1x02; MPN KF128-5.08-2P (Cixi Kefa); LCSC C474952
J2: D0 D1 D2 D3; TerminalBlock_Xinlaiya_XY350V-3.5_1x04; MPN XY350V-3.5-4P (Ningbo Xinlaiya); LCSC C557656
J3: D4 D5 GND; TerminalBlock_Kefa_KF350-3.5_1x03; MPN KF350-3.5-3P (Cixi Kefa); LCSC C474893
PS1: HLK-PM01; HiLink_HLK-PM01; MPN Hi-Link HLK-PM01, 5 V 0.6 A, 3 kVAC iso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; LCSC C209903
R1, R2, R3, R4, R5, R6: 10k; R_0603_1608Metric; MPN 0603WAF1002T5E; LCSC C25804
R11, R12, R13, R14, R15, R16: 1k; R_0603_1608Metric; MPN 0603WAF1001T5E; LCSC C21190
RV1: 275VAC; RV_TDK_SIOV_CU3225; MPN TDK SIOV B72650M0271K072 (CU3225K275G2)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; LCSC C211106
U1: XIAO ESP32-C6; XIAO-ESP32-C6-SMD-EdgePads; MPN Seeed Studio XIAO ESP32-C6 (113991254)

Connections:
+3V3: R1.1, R2.1, R3.1, R4.1, R5.1, R6.1, U1.12 (3V3)
+5V: C2.1, D1.1 (K), U1.14 (5V)
+5V_PSU: C1.1, D1.2 (A), PS1.4 (+Vout)
AC_L: F1.2, PS1.1 (AC/L), RV1.1
AC_L_IN: F1.1, J1.1
AC_N: J1.2, PS1.2 (AC/N), RV1.2
D0: R1.2, R11.2, U1.1 (D0)
D1: R2.2, R12.2, U1.2 (D1)
D2: R3.2, R13.2, U1.3 (D2)
D3: R4.2, R14.2, U1.4 (D3)
D4: R5.2, R15.2, U1.5 (D4)
D5: R6.2, R16.2, U1.6 (D5)
GND: C1.2, C2.2, C11.2, C12.2, C13.2, C14.2, C15.2, C16.2, J3.3, PS1.3 (-Vout), U1.13 (GND)
IN_D0: C11.1, J2.1, R11.1
IN_D1: C12.1, J2.2, R12.1
IN_D2: C13.1, J2.3, R13.1
IN_D3: C14.1, J2.4, R14.1
IN_D4: C15.1, J3.1, R15.1
IN_D5: C16.1, J3.2, R16.1

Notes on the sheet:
MAINS SIDE - 100-240 V AC. Keep >= 6 mm to everything on the low-voltage side.
F1 before everything; RV1 across L/N after the fuse, at the module input.
5 V from the certified, isolated HLK-PM01 (3 kV AC). D1 stops USB back-feeding it.
XIAO ESP32-C6. Pin map fixed by the firmware: D0-D5 = GPIO 0, 1, 2, 21, 22, 23.
D6-D10 unused. BOOT (GPIO9) and RESET are the buttons on the XIAO itself.
Each input: 10k pull-up at the pin, 1k series, 10nF at the terminal side.
Closed wall switch = pin to GND = active. Terminals are LOW VOLTAGE ONLY (3.3 V).
NEVER connect USB while the board is on mains. Uncertified design: installation by an electrician.

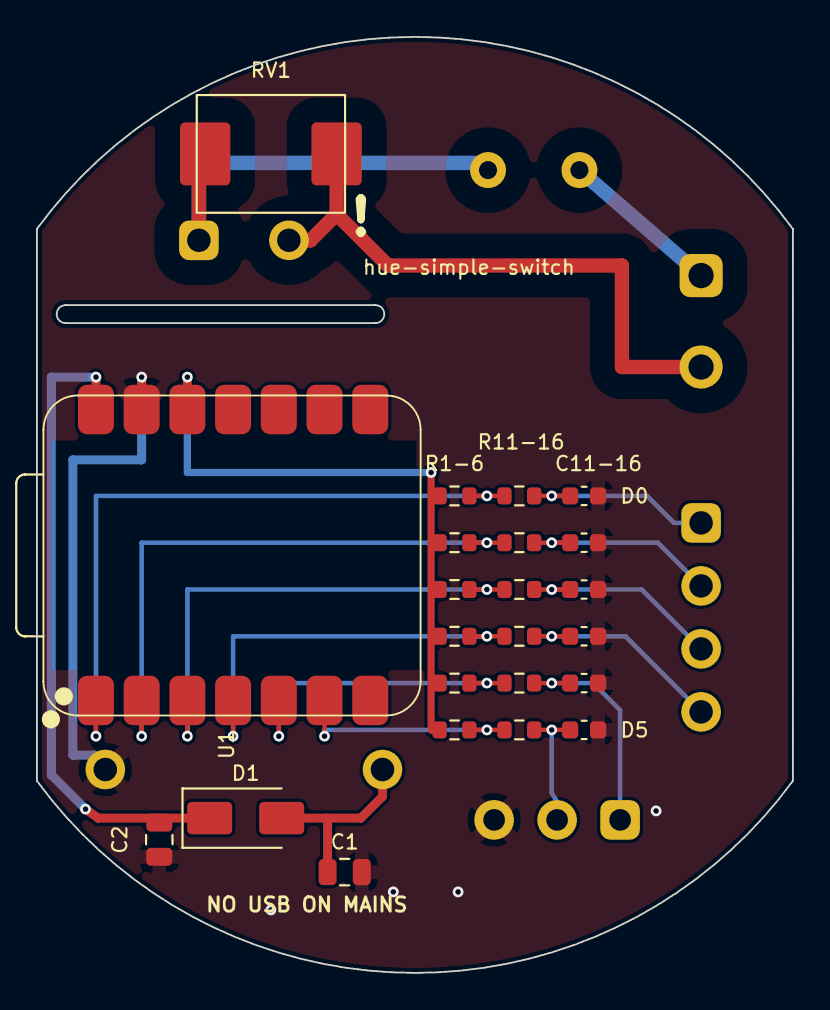
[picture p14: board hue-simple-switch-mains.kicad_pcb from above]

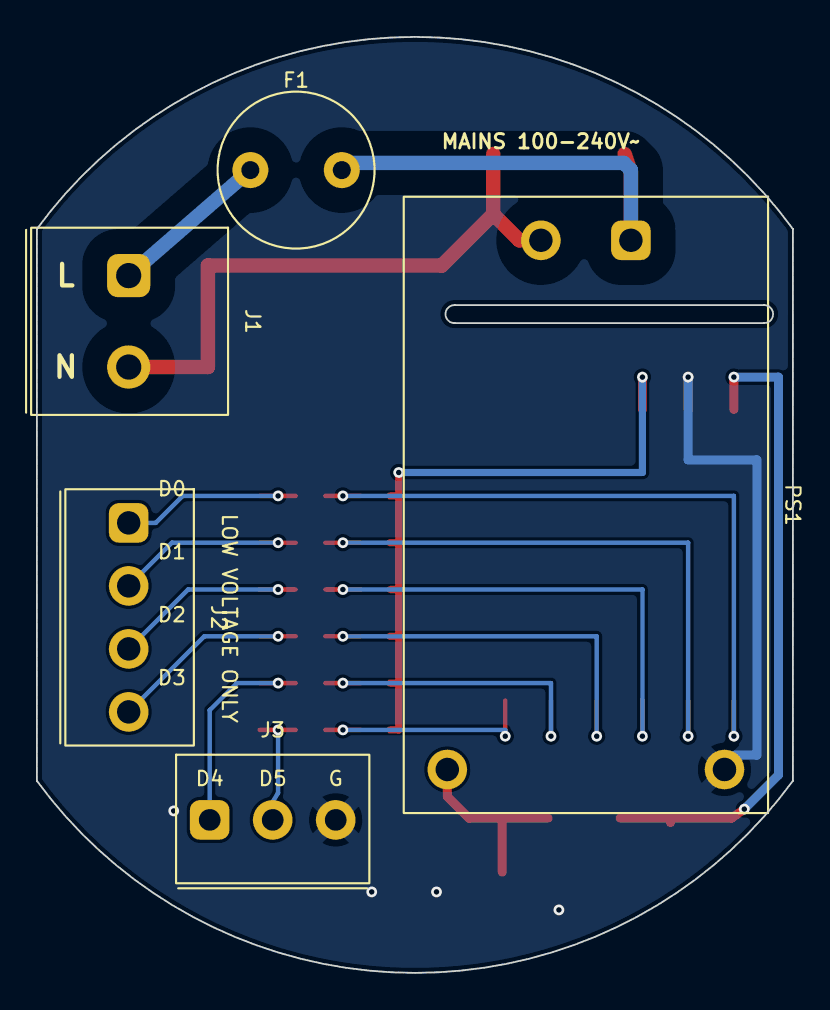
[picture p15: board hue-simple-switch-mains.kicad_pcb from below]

Board: 2 copper layers, 42.0 x 52.0 mm, 28 parts (5 on the bottom side), 19 nets.

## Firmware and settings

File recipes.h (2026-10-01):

#pragma once

#include <Preferences.h>
#include <nvs.h>
#include <string.h>
#include <freertos/FreeRTOS.h>
#include <freertos/semphr.h>
#include "json_util.h"

// Recipes and channel settings in NVS: the GPIO only reads this, never Vercel.

// 7 channels (BOOT, D0-D5) x at most 3 recipes each: the console never builds more.
static const uint8_t kMaxRecipes = 21;
static const uint8_t kMaxSceneTargets = 8;
// At least the channel count (7).
static const uint8_t kMaxChannelSettings = 8;

struct HueRecipe {
  char channelId[12];
  char event[16];
  char action[16];
  char rtype[16];
  char rid[40];
  // recall_scene: the scene list (targets[], or the old single scene target). rtype/rid unused.
  uint8_t sceneCount;
  char scenes[kMaxSceneTargets][40];
};

enum ChannelSettingKind : uint8_t { CHK_NONE = 0, CHK_MAINTAINED = 1, CHK_MOMENTARY = 2 };
// Toggle switch only: CHF_SET = the lever sets on or off (no "flip", or a value this firmware
// does not know); CHF_TOGGLE = each flip toggles ("flip": "toggle", since 0.8.0).
enum ChannelSettingFlip : uint8_t { CHF_SET = 0, CHF_TOGGLE = 1 };

struct ChannelSetting {
  char id[12];
  uint8_t kind;
  uint8_t flip;
};

// One config: recipes plus channels[]. fromConsole false = the old payload (no channels[]):
// compiled defaults for every pin.
struct RecipeConfig {
  HueRecipe recipes[kMaxRecipes];
  uint8_t recipeCount;
  ChannelSetting channels[kMaxChannelSettings];
  uint8_t channelCount;
  bool fromConsole;
};

inline HueRecipe gRecipes[kMaxRecipes];
inline uint8_t gRecipeCount = 0;
inline ChannelSetting gChannelSettings[kMaxChannelSettings];
inline uint8_t gChannelSettingCount = 0;
inline bool gChannelsFromConsole = false;
// Bumped on every change of recipes or channels; the GPIO loop re-reads its channel modes.
inline volatile uint32_t gRecipesGen = 0;
inline uint32_t gRecipeRev = 0;
inline String gRecipeBridgeId;
inline volatile bool gNeedConsoleSync = false;
inline volatile uint32_t gNvsEpoch = 0;
inline SemaphoreHandle_t gRecipesMux = nullptr;
// Parse buffer (console task and boot only): too big for the task stack.
inline RecipeConfig gRecipeStage;

inline void recipesMuxEnsure() {
  if (!gRecipesMux) {
    gRecipesMux = xSemaphoreCreateMutex();
  }
}

inline void recipesLock() {
  recipesMuxEnsure();
  if (gRecipesMux) {
    xSemaphoreTake(gRecipesMux, portMAX_DELAY);
  }
}

inline void recipesUnlock() {
  if (gRecipesMux) {
    xSemaphoreGive(gRecipesMux);
  }
}

inline bool recipeEventOk(const char *e) {
  return e && (strcmp(e, "on") == 0 || strcmp(e, "off") == 0 || strcmp(e, "double_click") == 0 ||
               strcmp(e, "short") == 0 || strcmp(e, "hold") == 0);
}

// dim needs a release to stop the ramp: hold only.
inline bool recipeActionOk(const char *a, const char *event) {
  if (a && strcmp(a, "dim") == 0) {
    return event && strcmp(event, "hold") == 0;
  }
  return a && (strcmp(a, "on") == 0 || strcmp(a, "off") == 0 || strcmp(a, "recall_scene") == 0 ||
               strcmp(a, "toggle") == 0);
}

inline bool recipeRtypeOk(const char *r) {
  return r && (strcmp(r, "light") == 0 || strcmp(r, "grouped_light") == 0);
}

inline void recipeCopyField(char *dst, size_t n, const char *src) {
  if (!dst || n == 0) {
    return;
  }
  if (!src) {
    dst[0] = 0;
    return;
  }
  strncpy(dst, src, n - 1);
  dst[n - 1] = 0;
}

// NVS keeps the wire shape, without scene names, one blob per channel (key c_<id>): the
// channel's setting (console config only) and its recipes. "n" is the recipe count, so a
// truncated or mixed-up blob is caught on load. Caller holds the lock.
inline String recipesChannelJson(const char *id) {
  uint8_t n = 0;
  for (uint8_t i = 0; i < gRecipeCount; i++) {
    if (strcmp(gRecipes[i].channelId, id) == 0) {
      n++;
    }
  }
  String s = "{\"n\":";
  s += String(n);
  if (gChannelsFromConsole) {
    for (uint8_t i = 0; i < gChannelSettingCount; i++) {
      if (strcmp(gChannelSettings[i].id, id) != 0) {
        continue;
      }
      s += ",\"channels\":[{\"id\":";
      jsonAppendEscaped(s, gChannelSettings[i].id);
      s += ",\"kind\":";
      jsonAppendEscaped(s, gChannelSettings[i].kind == CHK_MOMENTARY ? "momentary" : "maintained");
      if (gChannelSettings[i].flip == CHF_TOGGLE) {
        s += ",\"flip\":\"toggle\"";
      }
      s += "}]";
      break;
    }
  }
  s += ",\"recipes\":[";
  bool first = true;
  for (uint8_t i = 0; i < gRecipeCount; i++) {
    const HueRecipe &r = gRecipes[i];
    if (strcmp(r.channelId, id) != 0) {
      continue;
    }
    if (!first) {
      s += ',';
    }
    first = false;
    s += "{\"channelId\":";
    jsonAppendEscaped(s, r.channelId);
    s += ",\"event\":";
    jsonAppendEscaped(s, r.event);
    s += ",\"action\":";
    jsonAppendEscaped(s, r.action);
    if (r.sceneCount) {
      s += ",\"targets\":[";
      for (uint8_t k = 0; k < r.sceneCount; k++) {
        if (k) {
          s += ',';
        }
        s += "{\"rtype\":\"scene\",\"rid\":";
        jsonAppendEscaped(s, r.scenes[k]);
        s += '}';
      }
      s += "]}";
    } else {
      s += ",\"target\":{\"rtype\":";
      jsonAppendEscaped(s, r.rtype);
      s += ",\"rid\":";
      jsonAppendEscaped(s, r.rid);
      s += "}}";
    }
  }
  s += "]}";
  return s;
}

inline void recipeSceneTargetOne(const char *obj, void *ctx) {
  HueRecipe *r = static_cast<HueRecipe *>(ctx);
  if (!r || r->sceneCount >= kMaxSceneTargets) {
    return;
  }
  char rtype[16];
  char rid[40];
  if (!jsonGetString(obj, "rtype", rtype, sizeof(rtype)) || strcmp(rtype, "scene") != 0) {
    return;
  }
  if (!jsonGetString(obj, "rid", rid, sizeof(rid)) || !rid[0]) {
    return;
  }
  recipeCopyField(r->scenes[r->sceneCount], sizeof(r->scenes[0]), rid);
  r->sceneCount++;
}
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

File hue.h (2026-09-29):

#pragma once

#include <HTTPClient.h>
#include <NetworkClientSecure.h>
#include "config.h"
#include "json_util.h"

#ifndef HUE_BRIDGE_IP
#define HUE_BRIDGE_IP ""
#endif
#ifndef HUE_APP_KEY
#define HUE_APP_KEY ""
#endif

// IP and application key at runtime (mDNS / NVS / pairing).
extern String gHueBridgeIp;
extern String gHueAppKey;

// Bridge address, application key and Bridge id, copied out of the loop's Strings (these two
// and gHueBridgeId): the Hue worker and console tasks use their own copy while the loop re-pairs
// or clears them. The Clip v2 calls below need only the address and key.
struct HueCreds {
  char ip[16];  // dotted IPv4, at most 15 characters
  char key[64];
  char bid[40];  // Bridge id (16 hex characters on current Bridges)
};

inline bool hueCredsOk(const HueCreds &c) { return c.ip[0] && c.key[0]; }

// Pairing state for the LED. RAM: lost at boot. No extra GET.
inline volatile bool gHueKeyUsable = false;
inline volatile bool gHueIpUsable = false;
inline volatile bool gHueAuthRejected = false;
// After receiving the key from the Bridge button, an immediate 401 does not stick.
inline unsigned long gHueAuthGraceUntil = 0;
inline volatile bool gHuePairing = false;
inline volatile bool gHuePairTimeout = false;
inline volatile bool gHueBridgeMissing = false;

// 401/403 with the key (except "link button not pressed") drop to #3, a GPIO PUT too.
// Without the key (/api/config, discovery) it does not prove the saved key is bad.
// A 200 with the key recovers. Timeout, 5xx or Bridge down do not count here.
inline void hueAuthGraceArm(unsigned long ms) {
  gHueAuthGraceUntil = millis() + ms;
  gHueAuthRejected = false;
}

inline bool hueAuthGraceOpen() {
  return (long)(gHueAuthGraceUntil - millis()) > 0;
}

inline void hueNoteAuth(int code, const String *body, bool withKey) {
  if (code == HTTP_CODE_UNAUTHORIZED || code == HTTP_CODE_FORBIDDEN) {
    if (!withKey || hueAuthGraceOpen()) {
      return;
    }
    if (body && body->indexOf("link button not pressed") >= 0) {
      return;
    }
    gHueAuthRejected = true;
    return;
  }
  if (withKey && code == HTTP_CODE_OK) {
    gHueAuthRejected = false;
    gHuePairTimeout = false;
    gHueBridgeMissing = false;
  }
}

// The Bridge uses a self-signed certificate; Clip v2 requires local HTTPS.
// setInsecure() skips validating that CA (LAN only, not cloud).

// key: sent as hue-application-key; nullptr = a call without the key (discovery, pairing).
inline int hueHttpKey(const String &url, const char *method, const char *body, String *response, const char *key,
                      bool insecure) {
  const bool withKey = key != nullptr;
  NetworkClientSecure client;
  if (insecure) {
    client.setInsecure();
  } else {
    client.useBuiltinCACertBundle();
  }
  HTTPClient http;
  if (!http.begin(client, url)) {
    return -1;
  }
  http.setTimeout(8000);
  if (withKey && key[0]) {
    http.addHeader("hue-application-key", key);
  }
  if (body) {
    http.addHeader("Content-Type", "application/json");
  }
  int code = -1;
  if (strcmp(method, "GET") == 0) {
    code = http.GET();
  } else if (strcmp(method, "POST") == 0) {
    code = http.POST(body ? String(body) : String());
  } else {
    code = http.PUT(body ? String(body) : String());
  }
  String denied;
  const String *noted = nullptr;
  if (response) {
    *response = http.getString();
    noted = response;
  } else if (code == HTTP_CODE_UNAUTHORIZED || code == HTTP_CODE_FORBIDDEN) {
    denied = http.getString();
    noted = &denied;
  }
  http.end();
  hueNoteAuth(code, noted, withKey);
  return code;
}

// Loop task only (discovery, pairing): reads the saved key, which only the loop changes.
inline int hueHttp(const String &url, const char *method, const char *body, String *response, bool withKey,
                   bool insecure) {
  return hueHttpKey(url, method, body, response, withKey ? gHueAppKey.c_str() : nullptr, insecure);
}

inline int hueClipStream(const HueCreds &c, const char *resource, JsonDataSink &sink) {
  if (!hueCredsOk(c) || !resource) {
    return -1;
  }
  String url = "https://";
  url += c.ip;
  url += "/clip/v2/resource/";
  url += resource;
  NetworkClientSecure client;
  client.setInsecure();
  HTTPClient http;
  if (!http.begin(client, url)) {
    return -1;
  }
  http.setTimeout(20000);
  http.addHeader("hue-application-key", c.key);
  const int code = http.GET();
  String denied;
  const String *noted = nullptr;
  if (code == HTTP_CODE_OK) {
    http.writeToStream(&sink);
  } else if (code == HTTP_CODE_UNAUTHORIZED || code == HTTP_CODE_FORBIDDEN) {
    denied = http.getString();
    noted = &denied;
  }
  http.end();
  hueNoteAuth(code, noted, true);
  return code;
}

inline String hueResourceUrl(const HueCreds &c, const char *rtype, const char *rid) {
  String url = "https://";
  url += c.ip;
  url += "/clip/v2/resource/";
  url += rtype;
  url += "/";
  url += rid;
  return url;
}

inline bool hueParseOn(const String &body, bool *on) {
  return jsonHueOn(body.c_str(), on);
}

// bri (optional): dimming.brightness, -1 when the resource has none.
inline bool hueGetOn(const HueCreds &c, const char *rtype, const char *rid, bool *on, float *bri = nullptr) {
  if (!hueCredsOk(c) || !rtype || !rid || !on) {
    LOGLN("Hue GET: begin failed");
    return false;
  }
  String body;
  const int code = hueHttpKey(hueResourceUrl(c, rtype, rid), "GET", nullptr, &body, c.key, true);
  LOG("Hue GET %s/%s %d\n", rtype, rid, code);
  if (code != HTTP_CODE_OK) {
    LOGLN(body);
    return false;
  }
  if (!jsonHueOn(body.c_str(), on)) {
    LOGLN("Hue GET: could not parse on");
    LOGLN(body);
    return false;
  }
  if (bri && !jsonHueBrightness(body.c_str(), bri)) {
    *bri = -1;
  }
  return true;
}

inline bool huePut(const HueCreds &c, const char *rtype, const char *rid, const char *payload, const char *what) {
  if (!hueCredsOk(c) || !rtype || !rid) {
    LOGLN("Hue PUT: begin failed");
    return false;
  }
  String body;
  const int code = hueHttpKey(hueResourceUrl(c, rtype, rid), "PUT", payload, &body, c.key, true);
  LOG("Hue PUT %s/%s %d -> %s\n", rtype, rid, code, what);
  if (code != HTTP_CODE_OK) {
    LOGLN(body);
    return false;
  }
  return true;
}

inline bool hueSetOn(const HueCreds &c, const char *rtype, const char *rid, bool on) {
  return huePut(c, rtype, rid, on ? "{\"on\":{\"on\":true}}" : "{\"on\":{\"on\":false}}", on ? "on" : "off");
}
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

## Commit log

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2026-09-19 Add BOOT toggle, Hue discovery, and on-device pairing
    BOOT (GPIO9) toggles one Clip v2 light over local HTTPS. The sketch
    finds the Bridge via mDNS, caches IP and app key in NVS, and can pair
    a key when the Bridge button is pressed. USB CDC TX timeout is 0 so
    boot is not blocked without a serial host.
2026-09-21 Poll the console off the GPIO path and keep last-good snapshots.
    [partitions.csv]
2026-09-21 Add Improv Serial and HUESET for USB web-setup.
    Product binary opens CDC with logs off, persists STA via Arduino, stores console token/url in NVS. CI exports installer parts and publishes the usb-installer release.
2026-09-21 Pump USB during boot so Improv survives DTR reset (0.2.4).
    Hue/mDNS no longer blocks setup. usbPoll stays up if STA is down. Leave README LED notes unstaged.
    [hue-simple-switch.ino]
2026-09-21 Keep CDC for Improv: gate Serial.printf behind LOG (0.2.5).
    SERIAL_DEBUG=0 no longer mixes Hue/console logs with Improv. TX timeout 100 ms.
    [channels.h, hue-simple-switch.ino, hue.h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]
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2026-09-22 Leave the LED on the new Hue key if the first check fails (0.2.10).
    [hue.h]
2026-09-23 Ask firmware agents to write changelog entries for the person using the switch.
2026-09-23 Point firmware agents at the console for the device contract and the installer bin workflow.
2026-09-24 CI: keep the console upload warn-only on transport failures.
    GitHub runs steps with bash -e. With curl unable to connect, resp.json
    is never written and the cat of it failed the step; a missing
    CHANGELOG.md failed it too. Disable errexit in that step so both print
    a warning during the transition.
2026-09-24 USB: add HUEBOOT to restart into the ROM bootloader; 0.2.11.
    HUEBOOT answers "HUEOK boot", flushes USB, waits 100 ms, sets the
    C6 force-download-boot flag and calls esp_restart(), so Devices can
    flash without the BOOT and RESET buttons (console
    docs/specs/usb-download-mode.md). Unknown lines still answer
    "HUEERR unknown". NVS and flash are untouched.
    Register names from the Arduino-ESP32 3.3.12 core,
    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
2026-09-24 Changelog 0.2.11: RESET is still pressed once after the write.
    The console does not restart the C6 after flashing (esptool skips the
    watchdog reset on the C6 because of a USB-Serial/JTAG bug), so only the
    BOOT button goes away. Same wording fixed in AGENTS.md and a usb.h
    comment. FIRMWARE_VERSION stays 0.2.11.
2026-09-26 Channel types from the console; 0.3.0.
    Reads channels[] (kind) from config and ignores pins it does not list; the
    old payload falls back to the compiled kinds. Push buttons: short on release
    at once without a double_click recipe, double_click on the second press, hold
    at 800 ms. BOOT with a hold recipe never re-pairs from the button. Scene lists
    (targets[]) cycle from the last scene per channel in NVS, cleared by off, skip
    404. Register no longer sends channels[].kind. Recipes move to an NVS blob.
    Spec: hue-switch-console docs/specs/simple-channel-types.md.
    [channels.h, hue-simple-switch.ino, hue.h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]
2026-09-26 Hold to dim on push buttons; 0.4.0.
    Per hue-switch-console docs/specs/simple-hold-dim.md: a hold recipe with
    action dim starts a Clip v2 dimming_delta ramp and sends stop on release.
2026-09-26 Config sync: report rev, console-paced polling; 0.4.1.
    GET /api/device/config sends &rev=<gRecipeRev>. 204 keeps NVS without
    reading a body. X-Poll-Sec (200/204) sets the next poll, clamped 30-3600 s;
    without it the old 1 min / 1 h constants apply, and a 401 waits 1 h. After
    NVS takes a new rev, poll once more right away so the console sees it.
    With recipes, register is still at most hourly. recipesSave reports NVS
    write failures. Console spec: docs/specs/config-sync.md.
    [recipes.h]
2026-09-26 Credits: list third-party components and send them with each release.
    THIRD_PARTY.json names the Arduino-ESP32 core 3.3.12 and its bundled
    ESP-IDF v5.5.5 with their licenses. The upload step now checks that every
    platform and library pinned in sketch.yaml is listed at the same version,
    and sends the file as the release credits (console spec docs/specs/credits.md).
2026-09-27 License the firmware as MIT
    Community open source: this firmware is MIT, the console is AGPL-3.0-only.
    Adds the LICENSE text and a README "License" section covering the
    third-party components in THIRD_PARTY.json, the LGPL Arduino-ESP32 core,
    and the Signify trademark notice. No FIRMWARE_VERSION bump; no board change.
2026-09-27 Open-source prep: contributing guide, issue forms, PR build check
    - CONTRIBUTING.md, issue forms (switch bug, feature idea) and a PR template.
    Contract and console issues are routed to hue-switch-console.
    - build.yml compiles pull requests (no upload, no secrets). The release
    stays in firmware.yml on push to main.
    - Personal machine paths are gone from AGENTS.md and docs; local paths move to
    a gitignored AGENTS.local.md.
    No FIRMWARE_VERSION bump; no board change.
2026-09-27 Code of conduct; no CLA
    - CODE_OF_CONDUCT.md: Contributor Covenant 2.1, reports to conduct@tineira.com.
    - CONTRIBUTING.md links it and states there is no CLA or sign-off.
    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
2026-09-27 Store rev only after the recipes saved (0.4.2) (#4)
    recipesSave wrote rev first. If the recipes blob then failed (NVS full)
    or power dropped in between, NVS held the new rev with the old recipes:
    after a reboot the switch reported the new rev, the console answered
    204, and the switch kept the old config until the next change. Now the
    blob and bridge id go first, rev last and only if they saved.
    Claude-Session: https://claude.ai/code/session_01AXiEXnafDAv4aArYFhPYeg
    [recipes.h]
2026-09-27 Run Hue gesture calls in a worker task (0.4.3) (#5)
    The GPIO loop only reads pins and posts (channel, event). A FreeRTOS task
    (hue_worker.h) looks up the recipe and makes the Clip v2 calls, so a slow
    or unplugged Bridge no longer stops the other channels from being read
    (console docs/problems.md P8).
    - One 4-entry FIFO per channel, served round-robin. Toggle switch: the
    lever position wins (off drops pending events, on drops a pending
    on/off; a dropped off still restarts the scene cycle). Push button:
    gestures queue in order and expire after 10 s. A release queues behind
    its hold, so a dim stop always follows its start.
    - Only the loop writes the Bridge IP and key; it publishes a co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
    [channels.h, hue-simple-switch.ino, hue.h]
2026-09-27 Read the Bridge from the published copy in the console task (0.4.4) (#7)
    The console task (consoleDoSync, consoleRegister, hueClipStream) read the
    gHueBridgeIp / gHueAppKey / gHueBridgeId Strings while the loop could
    reassign them during pairing, HUEPAIR or HUECLR, which can free the buffer
    mid-read. It now takes the fixed-size HueCreds copy the loop publishes under
    gHueJobMux (the same copy the Hue worker uses since 0.4.3), once per sync.
    HueCreds gains the Bridge id for this.
    afterWifiUp and huePairApplySync publish that copy before setting
    gNeedConsoleSync, so the sync they request never sees the old (or empty) key.
    No change to what is sent to the console.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
    [hue-simple-switch.ino, hue.h]
2026-09-28 Add inputs D3-D5: seven channels (0.5.0) (#8)
    * Add inputs D3-D5 (GPIO 21-23): seven channels (0.5.0)
    Implements the Simple section of the console spec
    docs/specs/simple-d0-d5-inputs.md.
    - channels.h: register boot and d0-d5. d3-d5 default to no kind on the
    old config payload (no channels[]), so an unwired pin never acts; they
    get the same INPUT_PULLUP setup as d0-d2.
    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
2026-09-28 Update over Wi-Fi from the console (0.6.0) (#9)
    Implements the Simple checklist of the console's docs/specs/ota.md.
    - Every config poll sends firmware=<FIRMWARE_VERSION>, and ota_error=<code>
    once after a failed attempt (dropped after a 200/204).
    - An `ota` block in any 200 is read before the rev check. After the poll's
    connection is closed and its body freed, the console task downloads the
    image from the console URL in NVS, streams it into the inactive slot while
    hashing it, and checks length and sha256 before Update.end(). NVS is never
    erased. Sequential download chosen from the heap test (spec §6).
    - Not started while an input is pressed / in a gesture or a Hue job is queued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
    [channels.h, hue-simple-switch.ino]
2026-09-28 Report an update cut off by a power cut (0.6.1) (#10)
    * Release 0.6.1: first update sent over Wi-Fi
    * Report a download cut off by a restart as ota_error=size (0.6.1)
    NVS ota/dl marks the download from just before the slot is first written
    until the attempt ends. Found at boot, the attempt is reported as size (fewer
    bytes than ota.size) and retried after an hour, instead of silently at once.
    ---------
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2026-09-29 Add mains carrier board and enclosure (hardware/) (#12)
    A carrier PCB that powers the XIAO ESP32-C6 from the mains inside a wall
    box, behind the existing switch, reading the wall switches on D0-D5.
    Firmware, pin map and console contract are unchanged.
    - Hi-Link HLK-PM01 (isolated 5 V), T500mA fuse, 275 VAC varistor, SS34 to
    the XIAO 5V pin; 10k pull-up, 1k series and 10nF per input.
    - Generated from hardware/scripts (design.py, layout.py) with KiCad 10:
    ERC clean, DRC clean with schematic parity and a 6 mm mains clearance
    and creepage rule.
    - Gerber zip for JLCPCB, BOM with LCSC numbers, CPL, schematic and
    assembly PDFs, STEP, renders.
    - Parametric OpenSCAD enclosure (46 x 56 x 26 m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
    [enclosure-base.stl, enclosure-lid.stl, enclosure.scad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]
2026-09-29 Keep board silkscreen text inside the outline (#13)
    Move the board name, the MAINS and NO USB ON MAINS labels and the U1/C2
    references inside the board edge, and separate the R1-6 / C11-16 legends.
    [hue-simple-switch-mains.kicad_pcb]
2026-09-29 Use one 4-way block for J2 (XY350V-3.5-4P) (#14)
    The BOM listed J2 as two KF350-3.5-2P blocks with quantity 1, so an order
    from it came one block short. Use a single 4-way 3.5 mm side-entry block
    (LCSC C557656); same footprint, pitch and height.
    [hue-simple-switch-mains-bom.csv, hue-simple-switch-mains.kicad_pcb, hue-simple-switch-mains.kicad_sch]
2026-09-29 Host tests for the JSON parsers; skip huge scene actions (0.6.4) (#18)
    Add test/host: plain C++ tests for json_util.h (field helpers,
    jsonEachArrayObject, the streaming JsonDataSink) and the config-poll
    parsers in recipes.h, built with g++ against minimal Arduino, NVS and
    FreeRTOS stubs. build.yml runs them with ASan and UBSan inside the
    compile job, so the required check name is unchanged.
    The tests found that JsonDataSink never skipped a scene's actions: it
    compared 11 bytes against the 10-byte key "actions":, so the match
    included the literal's NUL and never hit. Every scene was copied whole,
    and a scene whose actions exceed kMaxObj (20 KB) was dropped from the
    snapshot. Match the key wi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
    [json_util.h]
2026-09-29 CI: check credits on pull requests too (#19)
    Move the THIRD_PARTY.json vs sketch.yaml check out of firmware.yml into
    scripts/check-credits.py, same name and shape as hue-round-switch's,
    keeping this repo's check that each entry has name, version, license
    and url. build.yml runs it inside the compile job, so a PR that bumps
    the core or a library without updating the credits fails before merge;
    firmware.yml runs it first, before the build.
2026-09-29 Hold to dim: cycle up and down while held (0.7.0) (#22)
    Implements the Simple checklist of the console spec
    docs/specs/simple-dim-cycle.md. The first leg goes up from off or below
    30 %, down otherwise (or when the GET fails), and is timed from the
    distance left (3 s full sweep, at least 150 ms). While the button is
    held, the Hue worker turns around after each leg plus a 400 ms dwell
    with a full sweep the other way, with no GET between legs. The release
    cancels any pending turn-around and sends stop; after 30 s of hold the
    cycle stops by itself. A failed start or turn-around PUT stops the cycle
    and the release still sends stop. The per-channel last direction is gone.
    Turn-arounds are schedul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
    [channels.h, hue.h]
2026-09-29 Hold to dim: 250 ms pause at each end (0.7.1) (#23)
    The 400 ms dwell before turning around felt too long on the wall.
    [hue.h]
2026-09-29 JsonDataSink: keep the overflow flag once an object is dropped (#25)
    The sink cleared `overflow` as soon as the dropped object closed, so the
    snapshot's "object overflow" log line almost never fired. A per-object flag
    now tracks "this object did not fit"; the public `overflow` stays set for the
    rest of the stream and `dropped` counts the skipped objects, which
    hueStreamResource() logs. Debug log only: what the switch sends does not
    change. Host tests cover one and several drops, byte by byte and in chunks.
    Fixes #20
    [json_util.h]
2026-09-29 Host tests for the update offer parser (#26)
    * Host tests for the update offer parser
    Move OtaOffer, its globals, otaLooksLikeVersion, otaLooksLikeSha and
    otaParseOffer from ota.h into ota_offer.h, which has no device includes, so
    test/host builds it. ota.h includes it; no behavior change.
    New cases: a valid offer (spaces, newlines, field order, last field), absent
    or non-object `ota`, bad versions, bad sha256, relative vs absolute url, and
    size limits (size <= 0 or not a number, the 401-byte block limit, strings cut
    to their buffers).
    Fixes #21
    * Docs: host tests cover ota_offer.h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
2026-09-30 Check every mains-board footprint against its datasheet (#29)
    RV1 used a 1210 resistor footprint (3.2 x 2.5 mm), but the TDK SIOV
    CU3225K275G2 is 8.0 x 6.3 x 4.5 mm ("3225" is in hundredths of an inch);
    LCSC's package label was wrong. Other parts differed from their makers'
    drawings too.
    - New datasheet footprints in hardware/scripts/footprints.py:
    RV1 on TDK's land pattern (3.5 x 2.8 pads, 4.5 gap); PS1 on Hi-Link's
    drawing (rows 29.4, DC pins 15.4 apart, 1.3 drills for Ø0.8 ±0.2 pins);
    J1 KF128-5.08 (1.4 holes, 10.7 deep); J2 XY350V-3.5-4P and J3
    KF350-3.5-3P (6.9 deep). Box 3D models at datasheet size for those,
    the XIAO and the fuse, so the STEP heights are real.
    - RV1 moved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
    [enclosure-base.stl, enclosure-lid.stl, enclosure.scad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]
2026-09-30 3-board JLCPCB assembly panel, one-sided SMD, centred CPL (#30)
    * Add a 3-board JLCPCB assembly panel, one-sided SMD, centred CPL
    - R11-R16 move to the XIAO side, so every SMD part is on one side (no
    second stencil or double-sided assembly). Each input row is now
    pull-up, 1k, 10nF; the 10nF sits at the terminal side of the 1k.
    - build_panel.py: three boards on a 144 x 71 mm frame (over JLCPCB's
    70 x 70 minimum, so no extra rails), routed tabs with mouse bites,
    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
    [enclosure-base.stl, enclosure-lid.stl, hue-simple-switch-mains-board.step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]
2026-09-30 CPL: turn J2 and J3 by 180° for JLCPCB's models (#31)
    JLCPCB's 3D models for the XY350V (J2) and KF350 (J3) have the wire entry
    on the other side from KiCad's footprint convention; their KF128 model (J1)
    matches. In the placement preview J2 and J3 faced into the board. design.py
    now carries a per-part jlc_rot that build_all.py adds to the CPL rotation.
    [hue-simple-switch-mains-cpl.csv, hue-simple-switch-mains-panel-cpl.csv]
2026-09-30 Add a JLCPCB single-board BOM without the XIAO (#32)
    The single-board BOM in hardware/fab is the hand-assembly version and
    lists U1 (the XIAO, no LCSC part), which JLCPCB reports as missing from
    the CPL. hardware/fab/jlcpcb/hue-simple-switch-mains-single-bom.csv has
    JLCPCB's four columns and leaves U1 out, like the panel BOM.
    [hue-simple-switch-mains-single-bom.csv]
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2026-10-01 Toggle switch: each flip toggles (flip "toggle"), 0.8.0 (#33)
    A maintained channel with "flip": "toggle" in the config's channels[] runs
    the console's toggle-on-flip spec (§2.4): each debounced flip posts its
    event at once, both ways; with a double_click recipe a flip either way
    opens the 400 ms window and a second flip is double_click; no on fallback.
    Toggle-mode events queue in order and expire like push-button gestures,
    and a toggle restarts the scene cycle only when it turned the target off.
    A change of flip primes the pin like a change of kind. Absent or unknown
    flip = set, unchanged.
    The lever rules move to channel_input.h and the queue rules to
    hue_jobs.h, free of Arduino I/O and Fr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
    [channels.h, recipes.h]
2026-10-09 Hardware: multimeter checks before a board goes on mains (#34)
    TESTING.md lists the checks for an assembled carrier board (mains continuity,
    isolation, input resistors, first power-up through a series lamp) with the
    meter mode and expected reading for each, the readings from the first board,
    and the measuring mistakes that look like faults. The README links it and its
    status now says one board passed these checks without the XIAO.
2026-10-09 Hardware: isolation reading and XIAO checks from the first board (#35)
    Section 2 asked for OL on every isolation reading. With a Fluke 83 the first
    boards rise for about a minute and end near 24 MOhm, the same on every point
    and with or without the XIAO: that is the HLK-PM01. It now says so and tells a
    leak apart (a fixed, lower value). A new section 5 covers cleaning and the
    checks once the XIAO is soldered. The README status says the first board runs
    on mains with the XIAO.
2026-10-09 Hardware: test-point map for TESTING.md (#36)
    TESTING.md pointed at the plain top render. A new script draws callouts on it
    for every point the checks use, with pad positions read from the PCB, and
    shades the mains side; the XIAO and D1 pads get small tags on the board since
    they are too close together for callouts. build_all.py runs it after the
    renders, and it stops if a re-render moves the board off the measured mapping.
    [build_all.py, test_points.py]
2026-10-26 docs: archive the LED spec, point contract changes at console issues [skip ci]
    Moves docs/specs/finished/led-status.md to a frozen docs/archive/specs/ with an index; the README's Orange LED table stays the current description. AGENTS.md, CONTRIBUTING.md and README.md link the console's new docs/usb-protocol.md (USB commands) instead of its archived devices.md, cite the console README for release notes and uploads, send contract changes to a console "Contract change" issue, and state the no-specs-in-docs rule. Open work: GitHub issues.
2026-10-31 Hardware: withdraw the order files and correct the isolation claims (#37)
    GND copper sits 1.5 mm from mains copper, not the stated 6 mm. Remove the
    Gerbers, BOMs and CPLs from main, ignore them so build_all outputs are not
    recommitted, and replace the ordering steps with a withdrawal notice.
    Correct the README and TESTING claims: the first board later failed with no
    proven cause, 24 MOhm is not a pass value, and passing the multimeter checks
    does not show a board is safe. History is not rewritten.
2026-10-31 Hardware: make the 6 mm mains rules apply to zones and tracks (#38)
    The clause B.Pad_Type != 'NPTH, mechanical' skipped every item that is not
    a pad. Only test the pad type on pads, so the mouse-bite holes stay exempt.
    build_all.py now stops on the resulting DRC errors until the copper is
    fixed. That is intended. No board or fab file is regenerated here.
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
